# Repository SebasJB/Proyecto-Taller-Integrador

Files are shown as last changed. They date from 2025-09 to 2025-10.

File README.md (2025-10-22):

# Plataforma de interconexión y pruebas del SIWA

## EL-5610 – Taller Integrador

[]()
[]()
[]()
[]()

---

## 1. Introducción

<p align="justify">
Este sprint documenta la construcción física de la PCB del proyecto, desde el barrenado inicial (<em>drill</em>) hasta la soldadura SMD posterior al reflow. El objetivo es registrar, con trazabilidad, cada etapa del proceso junto con criterios de aceptación y evidencias visuales, de manera que la tarjeta quede lista para el plan de pruebas eléctricos y funcionales del siguiente sprint.
</p>

---

## 2. Integrantes

- Samuel Valdivia Mejias
- Sebastian Barrantes Perez
- Christopher Quiros Cisneros

---

## 3. Etapas de fabricación
### 3.1 Drill

La etapa de perforado o drill, consiste en taladrar todos los orificios para pines, tornillos y vías según el archivo de mecanizado. Aquí se definen los diámetros y la precisión de los taladros que conectarán las capas a través de metalización. En la siguiente imagen se observa el resultado del proceso de perforado.

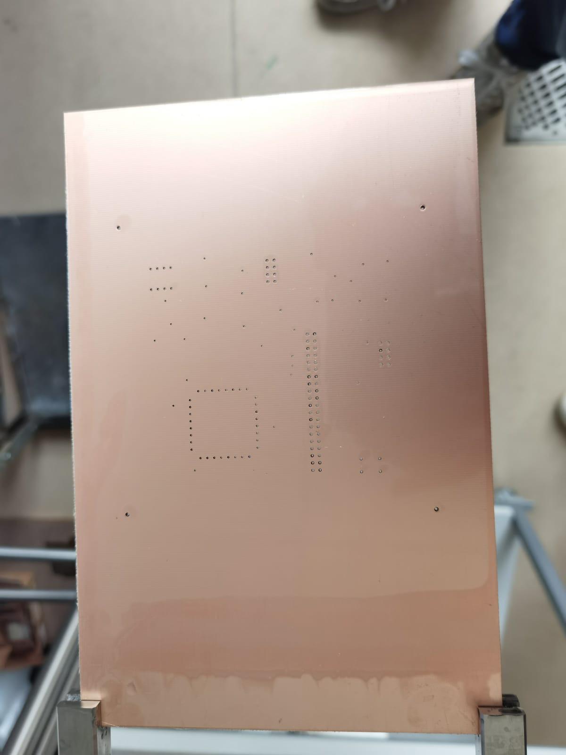
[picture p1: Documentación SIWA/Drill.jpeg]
PCB: Post drill
 <p align="center"> PCB: Post drill </p>

### 3.2 Metalización y Stencil

La metalización recubre las paredes de los orificios con cobre para crear vías eléctricas entre capas. El stencil se usa posteriormente para depositar pasta de soldar de forma precisa sobre pads SMD. En la siguiente imagen se aprecia el tablero después de metalizar.

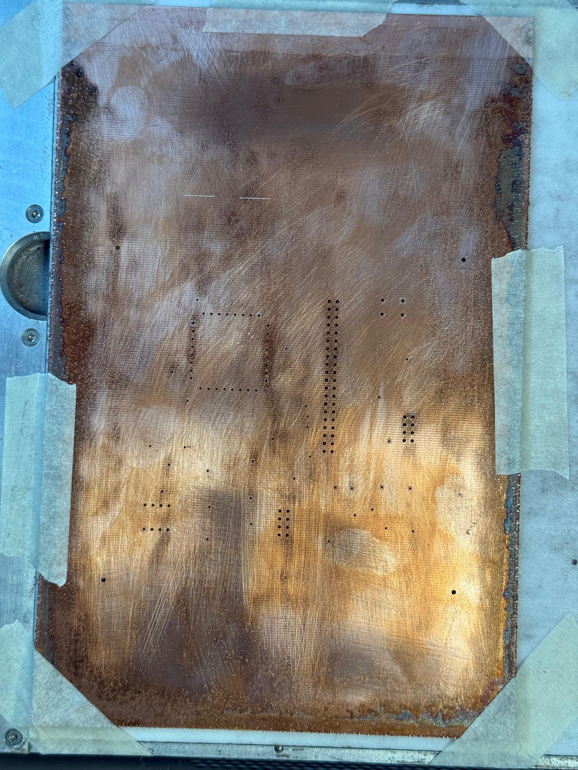
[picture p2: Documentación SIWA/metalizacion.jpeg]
PCB: Post metalizacion
 <p align="center"> PCB: Post metalizacion </p>

### 3.3 Endmill Bottom

El endmill bottom es un fresado de contorno o cavidades realizado por la cara inferior para definir bordes, islas o despejes de cobre mecánicos. En la siguiente imagen se muestra el resultado del fresado inferior.

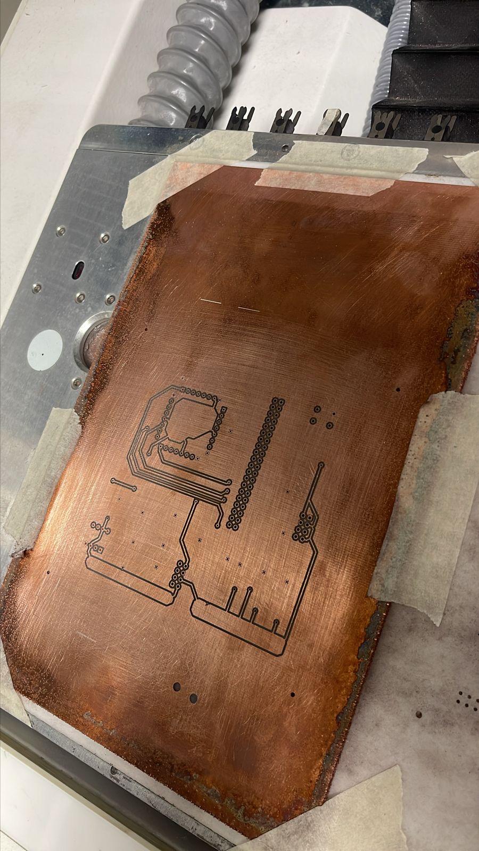
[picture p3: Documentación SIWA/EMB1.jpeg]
PCB: Post Endmill Bottom
 <p align="center"> PCB: Post Endmill Bottom </p>

### 3.4 Endmill Top

El endmill top realiza operaciones de fresado por la cara superior para definir pistas y pads. En las siguientes imágenes se observa el proceso durante la fabricación y el resultado final de la parte superior.

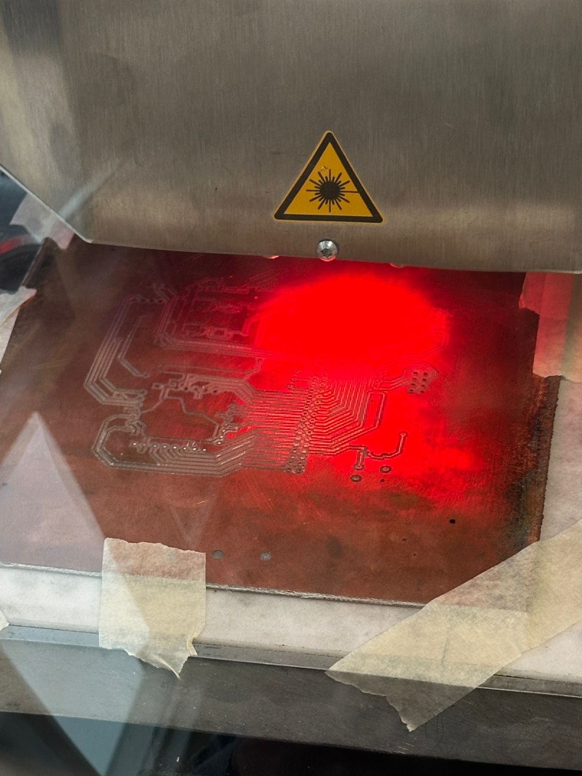
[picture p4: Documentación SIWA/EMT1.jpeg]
PCB: Endmill top durante fabricacion
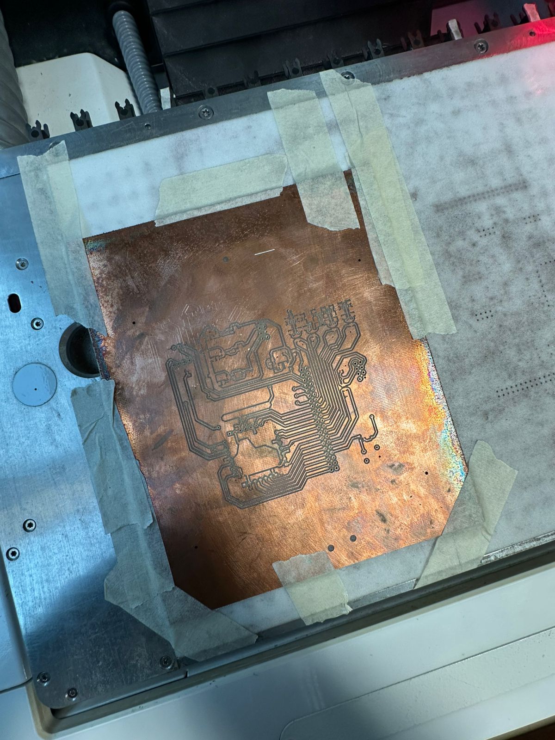
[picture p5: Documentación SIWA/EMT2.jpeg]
PCB: Post Endmill Top
 <p align="center"> PCB: Endmill top durante fabricacion </p>  <p align="center"> PCB: Post Endmill Top </p>

### 3.5 Verificación de aislamientos y cortos

En la verificación eléctrica se inspeccionan aislamientos entre redes y la ausencia de cortocircuitos, ya sea con multímetro o equipo de prueba de continuidad/hi-pot. En las siguientes imágenes se ven distintas revisiones realizadas.

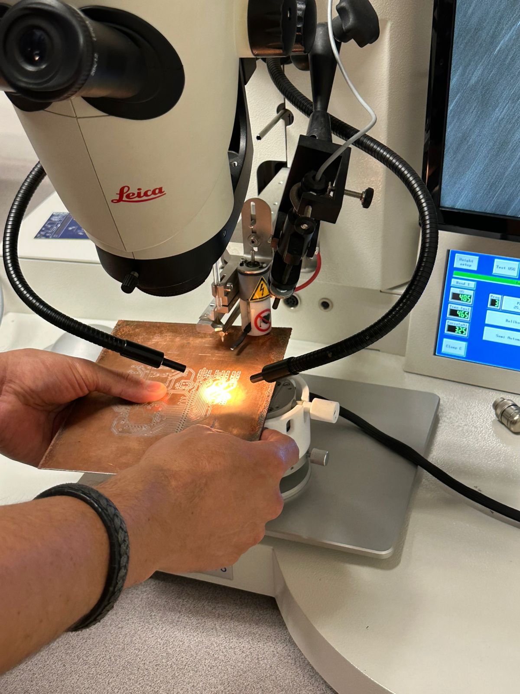
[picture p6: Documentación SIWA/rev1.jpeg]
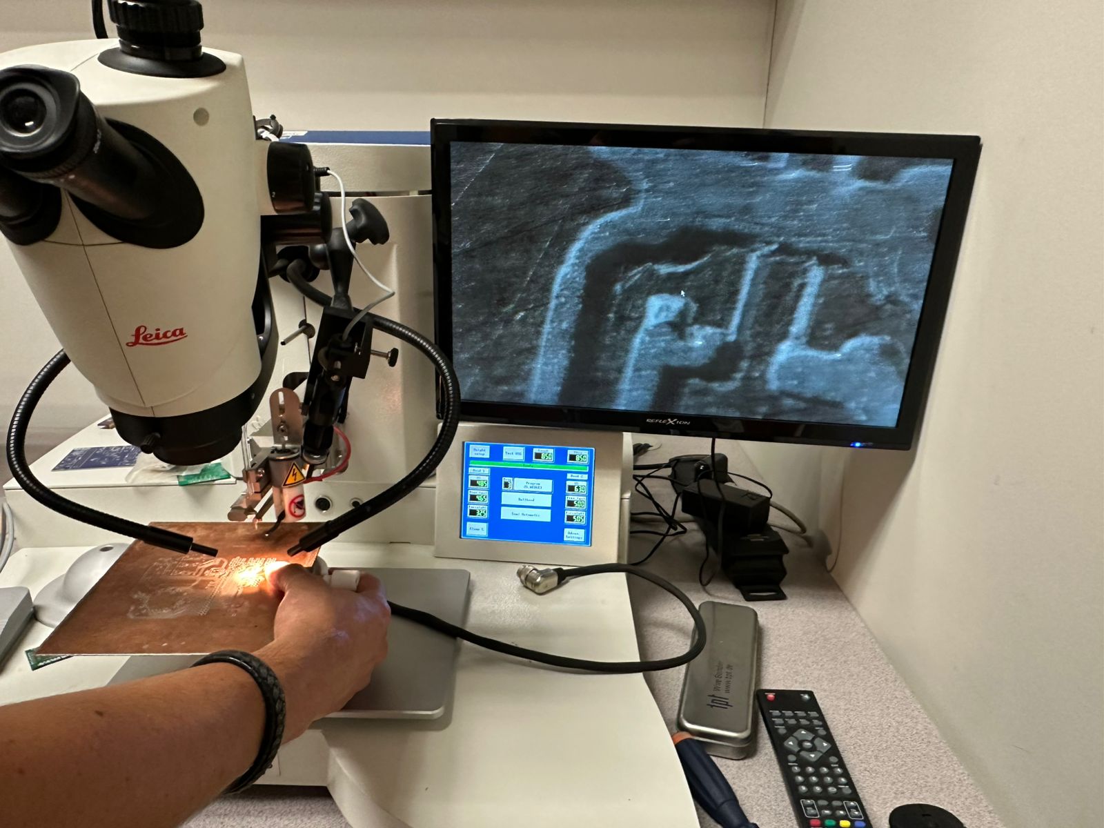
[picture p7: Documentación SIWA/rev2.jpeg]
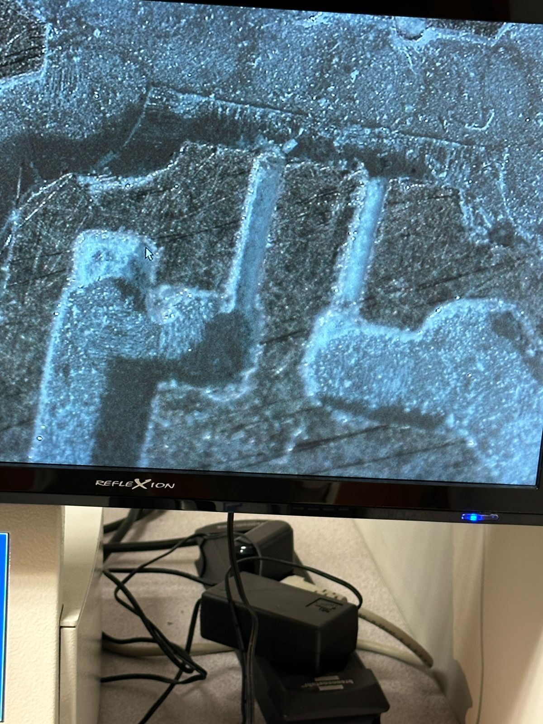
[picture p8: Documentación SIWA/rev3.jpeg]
 <p align="center"> PCB: Revision de cortos </p>  <p align="center"> PCB: Revision de cortos </p>  <p align="center"> PCB: Revision de cortos </p>

### 3.6 Soldermask y Silkscreen

La soldermask protege el cobre expuesto y define ventanas de soldadura sobre los pads; el silkscreen imprime referencias, logos y marcas de orientación. En las siguientes imágenes se muestran las caras superior e inferior tras aplicar soldermask y serigrafía.

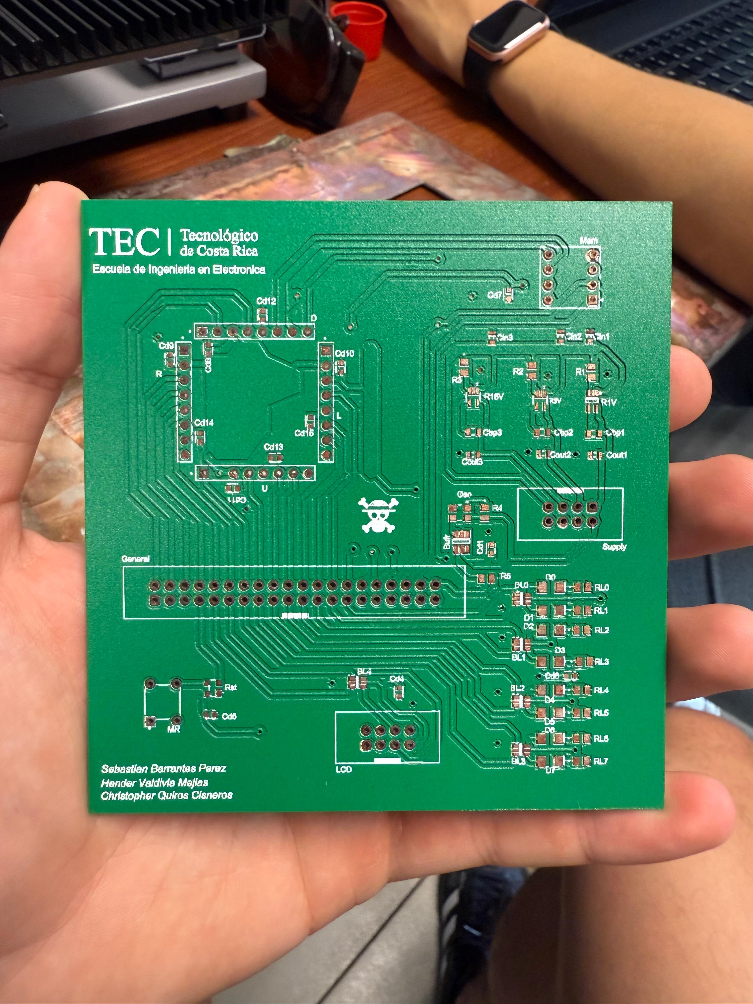
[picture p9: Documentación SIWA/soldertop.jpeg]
PCB: Post Soldermask Top
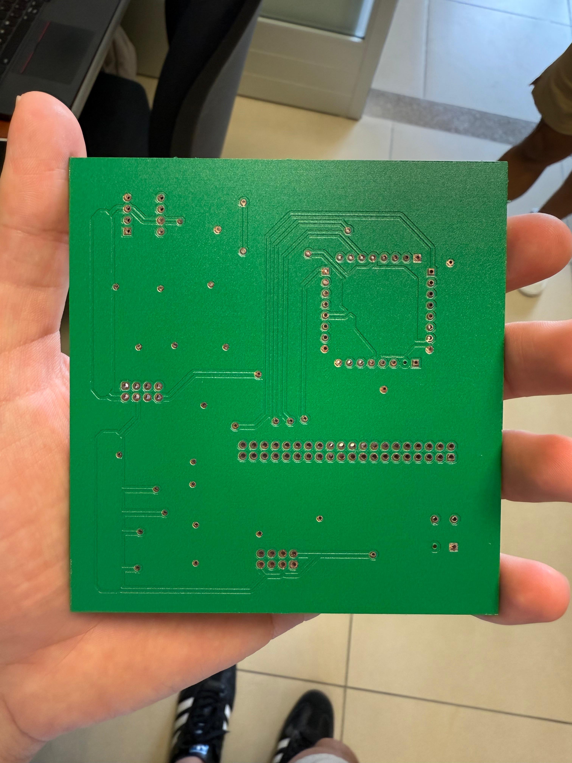
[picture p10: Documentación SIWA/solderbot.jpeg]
PCB: Post Soldermask Bottom
 <p align="center"> PCB: Post Soldermask Top </p>  <p align="center"> PCB: Post Soldermask Bottom </p>

### 3.7 Soldadura SMD

La soldadura SMD comprende el depósito de pasta con stencil, la colocación de componentes y el perfil de reflow en horno. En las siguientes imágenes se aprecia la aplicación de pasta, el pre-ensamble, el paso por horno y el resultado final de soldadura.

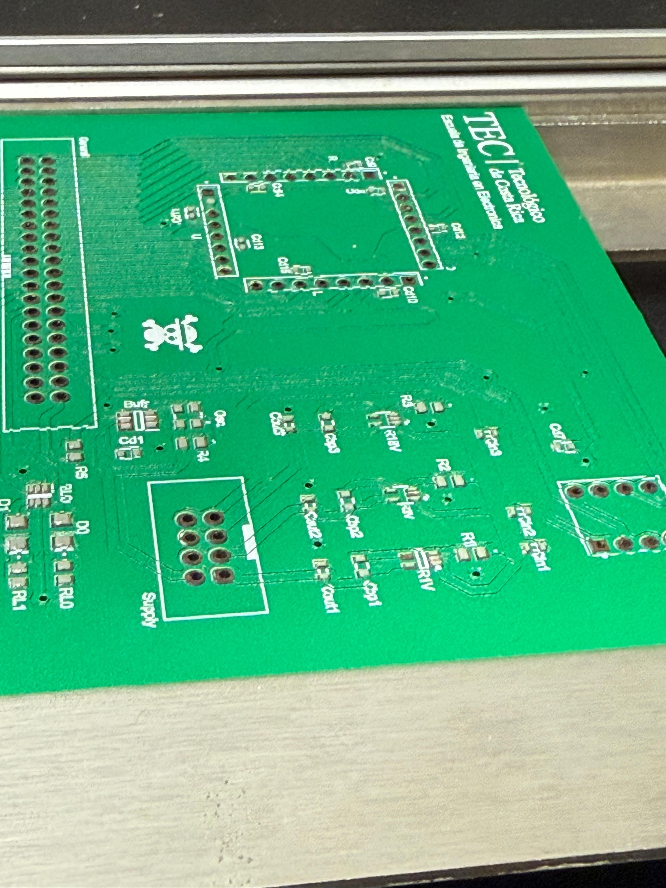
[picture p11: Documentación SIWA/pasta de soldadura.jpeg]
PCB: aplicacion de pasta de soldadura
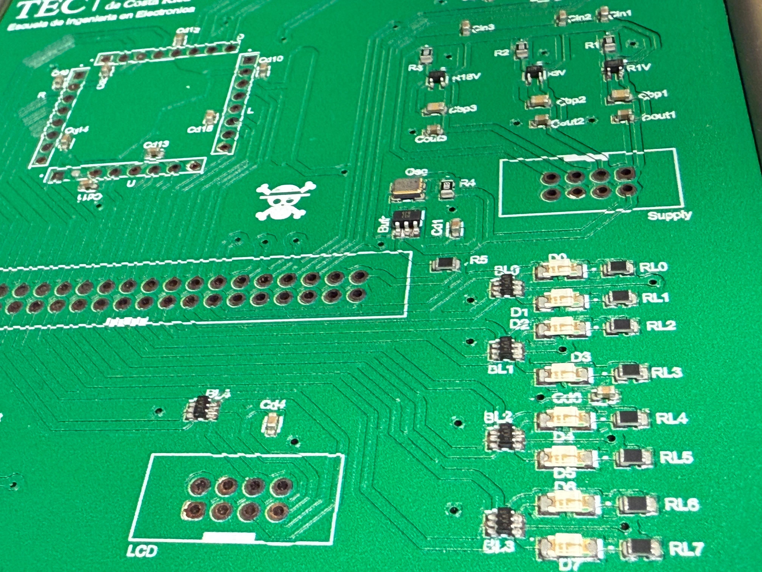
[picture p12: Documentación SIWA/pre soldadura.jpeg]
PCB: Presoldadura, componentes ya colocados
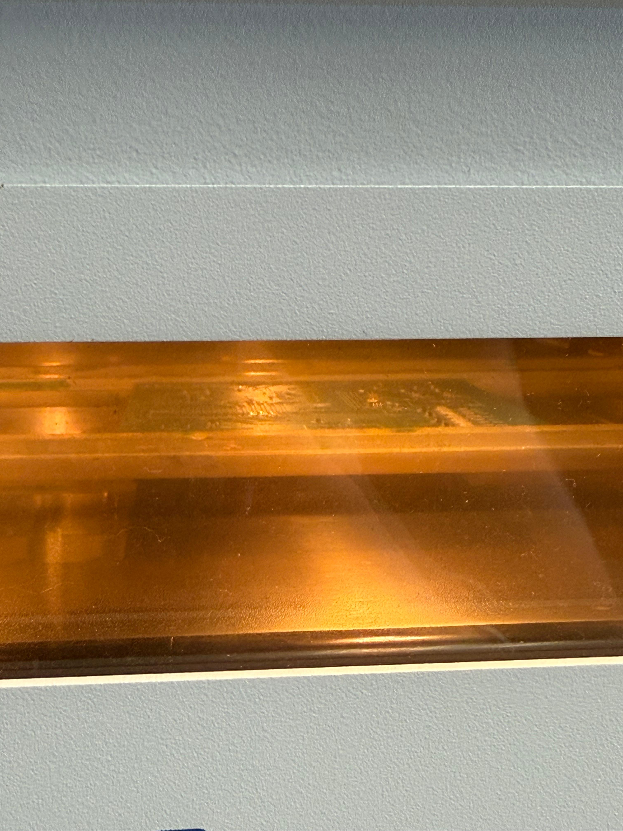
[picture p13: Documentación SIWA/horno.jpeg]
PCB: Proceso de soldado en el horno
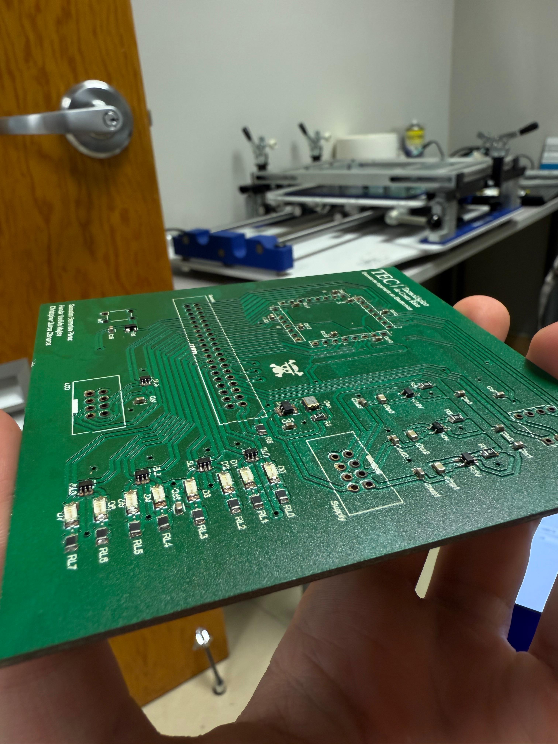
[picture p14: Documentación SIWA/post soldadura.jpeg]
PCB: Post Soldadura
 <p align="center"> PCB: aplicacion de pasta de soldadura </p>  <p align="center"> PCB: Presoldadura, componentes ya colocados </p>  <p align="center"> PCB: Proceso de soldado en el horno </p>  <p align="center"> PCB: Post Soldadura </p>

## 4. Erros y desafios

Durante el proceso de Endmill Top se encontró un corto en el buffer 0 de los LEDs el cual era causado por una mala remoción del cobre en la pista, se procedió a remover con un cincel especial.

Luego durante el proceso de soldadura SMD se generó otro cortocircuito que era causado por el contacto de dos soldaduras diferentes entre el pin de VDD y la salida hacia el LED 4 provocando una falla, luego de removerla con el cincel se pudo solucionar

Se encontró un probloema con los conectores hembra de la interfaz del SIWA que no entran en la placa por ser de forma cuadrada y ligeramente mas ancho que el espacio del hoyo para que entre los pines, se procedió a reducir el tamaño mediante limadura.

## 5. Test Plan – Verificación y Validación de la PCB
<p align="justify"> Este plan de pruebas detalla las verificaciones eléctricas y funcionales realizadas sobre la tarjeta fabricada. Cada prueba se identifica por un código <strong>(T-N)</strong> y busca confirmar la correcta operación de los subsistemas antes y después del montaje del ASIC. Las pruebas se ejecutan siguiendo una secuencia lógica: desde conectividad básica hasta validaciones funcionales completas con firmware de diagnóstico. 
De igual manera, de primer paso, se realizo la prueba del funcionamiento de la memoria:
</p>

<p align="center">
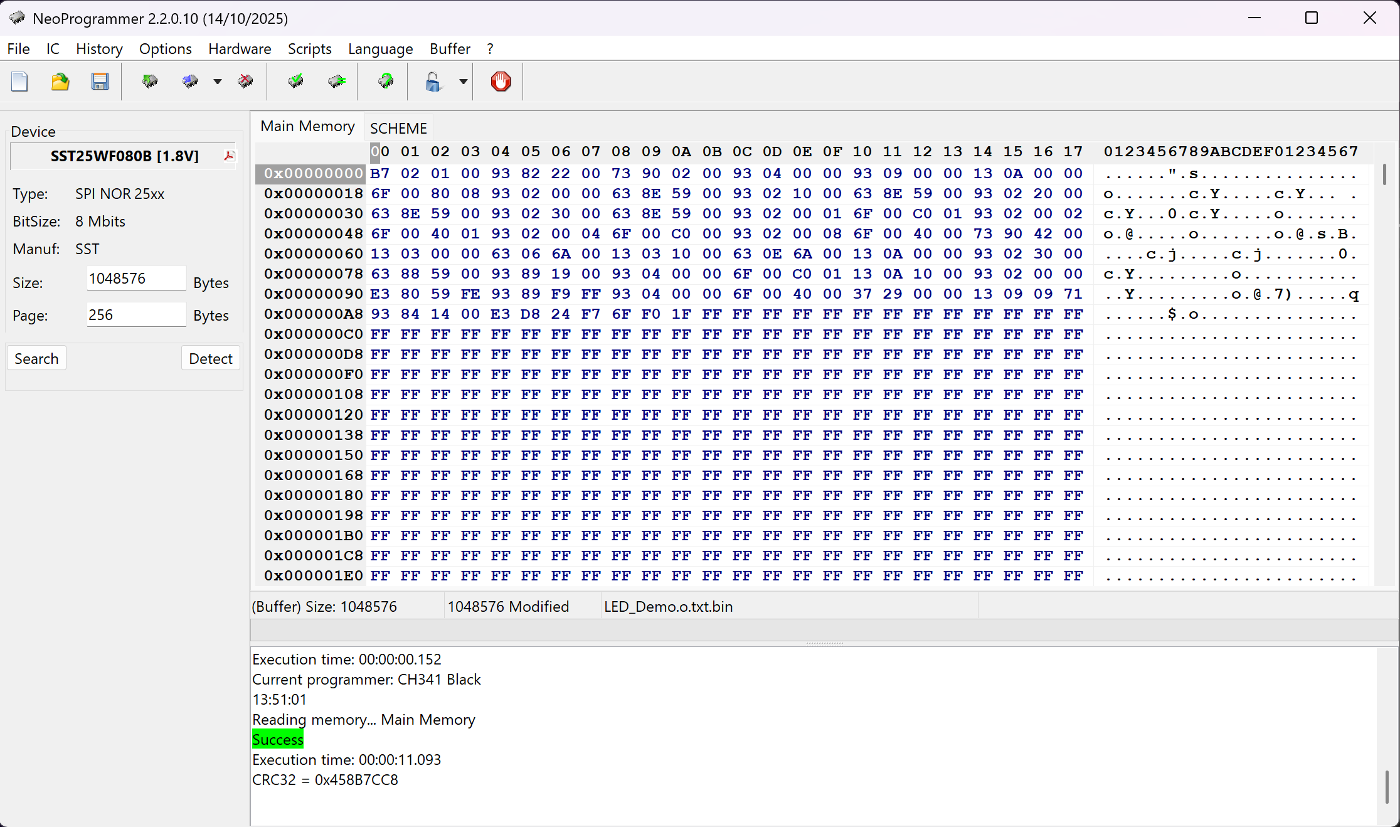
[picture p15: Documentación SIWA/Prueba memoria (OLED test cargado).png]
Prueba memoria (OLED test cargado)
  
</p>
<p align="center">
PCB: Post Soldadura

 ### 5.1. Instrumentación

- Fuente de laboratorio
- Multímetro digital (DMM)
- Osciloscopio 
- Cargas resistivas para 1 V, 1.8 V y 3 V
- Arduino para pruebas dinámicas
- Jumpers, divisores de tensión y convertidores de nivel

### 5.2 Conectividad por headers (T-0)
<p align="justify"> Antes de energizar la placa, se realiza una verificación minuciosa de continuidad utilizando los headers intermedios como puntos de prueba. Se confirma que cada módulo bufferizado (reguladores, LEDs, LCD, reloj y reset) tiene su camino eléctrico completo desde la entrada del buffer hasta la salida hacia la carga, y que no existen puentes inadvertidos a tierra o entre señales contiguas. Con el multímetro en modo continuidad y la placa sin alimentación, se comprueba cada par “entrada ↔ salida”, escuchando el pitido solo cuando corresponde según el esquemático. Se finaliza con una verificación de ausencia de corto entre rieles de alimentación y GND. </p>

**Objetivo:** Verificar continuidad entre headers, buffers y cargas, asegurando que no existan cortos entre rieles.

**Procedimiento:**
- Placa sin energía, DMM en continuidad.  
- Verificar headers intermedios y rieles de alimentación.  
- Confirmar ausencia de corto con GND.

**Criterio:**  
Todos los caminos coinciden con el esquemático y no hay cortos entre rieles.

### 5.3 Fuentes sin carga (T-1)
<p align="justify"> Con la placa sin cargas conectadas, se alimenta desde la fuente de laboratorio con límite de corriente ajustado. Se verifica que los tres reguladores (1.0 V, 1.8 V y 3.0 V) establecen sus tensiones nominales de forma estable y sin rizado excesivo. Se mide cada pista con multímetro (DC) y osciloscopio (AC) observando rizado y picos de arranque.</p>

**Objetivo:** Confirmar tensiones nominales y estabilidad sin carga.

| Riel | Tensión esperada | Ripple máx | Estado |
|:--|:--:|:--:|:--:|
| 3.0 V | 3.00 ± 3 % | < 50 mVpp | ☐ |
| 1.8 V | 1.80 ± 2 % | < 30 mVpp | ☐ |
| 1.0 V | 1.00 ± 2 % | < 20 mVpp | ☐ |

**Procedimiento:**

- Fuente de laboratorio a **Vin = 5.0 V**, GND común.  
- Medir con multímetro en el header de Alimentación:
  - Pin 1 (VDD10)
  - Pin 5 (VDD18)
  - Pin 3 (VDD30) 
- Medir cada pin en su header de salida con Multímetro y osciloscopio (AC acoplado).
  
**Criterio:** Las tres salidas están dentro de tolerancia y con rizado menor al límite.

### 5.4 Fuentes con carga (T-2)
<p align="justify"> Se conectan cargas resistivas a cada pista, una por vez, para validar la capacidad de regulación y estabilidad bajo demanda. Se incrementa la corriente hasta el valor nominal de cada pista y se repiten las mediciones. Luego se aplica un escalón de carga observando la respuesta transitoria: la tensión no debe presentar sobre-/sub-tensión mayores al 5 % ni oscilar. </p>

**Objetivo:** Evaluar regulación bajo corriente nominal y respuesta a transientes.

**Procedimiento:**
**Conexión:**
- Conecta cargas resistivas en protoboard y usar jumpers para conectar de los pines de salida del header a la protoboard:  
  - 10 Ω → VDD10,  
  - 18 Ω → VDD18,  
  - 30 Ω → VDD30.  
- Medir caída de tensión con Multímetro.  
- Realizar un **step-load de 10 % a 100 % a 10 %** y observar overshoot < 5 %.  
 Para el step-load: **Conmutador y resistencias**
- 2 resistencias que representen 10 % y 100 % de carga (R1 y R2).
- 1 transistor NPN (2N2222, 2N3904) o MOSFET N (IRLZ44N, 2N7000).
- Una señal cuadrada con generador de señales.
- Conectar el generador de señales al transistor y luego medir los cambios de tensión con osciloscopio en cada una de las resistencias de carga.

**Criterio:** Tensiones y rizados se mantienen dentro del rango permitido.

### 5.5 Reset (T-3)
<p align="justify"> Se verifica que el circuito de reset genera un pulso limpio y responde ante condiciones de sub-tensión. Con la placa energizada, se mide en el header del reset mientras se acciona el pulsador. El nivel activo debe tener flancos definidos y duración suficiente para un reinicio completo. </p>

**Objetivo:** Verificar forma de pulso

**Procedimiento:**
1. Conecta osciloscopio entre **pin 7 (RSTO)** y **GND**.  
2. Alimenta la placa (Vin = 5 V).  
3. Presiona el pulsador **MR**.  
4. Observa en pantalla:  
   - Pulso activo **bajo** (≈ 100–200 ms).  
   - Nivel alto estable (3 V) tras liberación. 

**Criterio:** Pulso limpio, sin rebotes y a nivel correcto

### 5.6 Reloj de cristal y buffer (T-4)
<p align="justify"> Se verifica que el oscilador arranca correctamente y entrega la frecuencia nominal, con distribución adecuada por el buffer. La señal medida en el header debe tener forma limpia, duty-cycle cercano al 50 % (40–60 % admisible) y frecuencia dentro de la tolerancia del cristal (± 100 ppm ). </p>

**Objetivo:** Confirmar frecuencia y duty-cycle del oscilador con buffer.

**Pines:**  
- **CLK0** → pin 40  
- **GND** → pin 25  
- Alimentación: VDD18 (pin 4 del header de alimentación)

**Procedimiento:**
1. Colocar la sonda del osciloscopio en **pin 40 (CLK0)**.  
2. Alimentar la placa conectando el pin 1 al 2.  
3. Observa forma de onda.
- Alimentar el circuito y medir en el header de salida del buffer (pin 40).  
- Verificar que la frecuencia sea de **20.000 MHz ± 50 ppm**, un ciclo de trabajo entre 40–60 %, amplitud cercana a 3 Vpp.  

**Criterio:** Señal estable, libre de deformaciones y en frecuencia correcta.

### 5.7 LEDs bufferizados con Arduino (T-5)
<p align="justify"> Se valida la etapa de buffer y el camino hacia los LEDs utilizando un Arduino como generador de señales. Con tierra común, se inyectan señales ON/OFF y PWM (1 kHz) desde el header de control. Se observa que cada LED conmute y varíe de brillo sin parpadeos o incoherencias. </p>

**Objetivo:** Validar respuesta de buffers y polaridad de LEDs.

**Procedimiento:**
- GND común entre Arduino y placa.  
- Enviar secuencias de ON/OFF para probar encendido y apagado
- Enviar un PWM de 1 kHz para probar el brillo.
  
**Entradas de control:** pines 27: LED0, 25: LED1, 23: LED2, 21: LED3, 19: LED4, 17: LED5, 15: LED6 y 13: LED7   
**Salida visible:** cada LED D1–D8  
**Alimentación:** VDD30 (pin 6 del header de alimentación) 

**Criterio:** Todos los LEDs encienden, varían brillo y no presentan parpadeo.
### 5.8 LCD/OLED bufferizado con Arduino (T-6)
<p align="justify"> El display se valida mediante el header intermedio, usando el Arduino para generar la secuencia de inicialización y los patrones de prueba. SSe conectan MOSI/SCLK/CS/DC/RST respetando niveles de 3.3 V. Se inicializa el controlador y se muestra un patrón o texto. </p>

**Objetivo:** Confirmar inicialización y escritura básica vía Arduino.
**Pines:**

- LCD0 → pin 9
- LCD1 → pin 11
- Alimentación: VDD30 (pin 4 del header de alimentación)
  
**Procedimiento:**

- Conectar Arduino a SDA/SCL/RES del header con resistencias de pull-up de 4.7 kΩ a pin 9 y 11.
- Usar librerías y comandos básicos del dispositivo en US2066.
- Enviar un PWM de 1 kHz para probar el brillo.

**Criterio:** Pantalla inicializa y muestra texto sin artefactos o pérdida de contraste.

### 5.9 Memoria en base DIP con apoyo de Arduino (T-7)
<p align="justify"> Dado que la memoria no posee header intermedio, se prueba directamente sobre el zócalo DIP con un Arduino. Para memorias seriales (SPI/I²C), se realiza una escritura/lectura de patrones simples (0xAA, 0x55, 0x00, 0xFF). Para memorias paralelas, se controla un subconjunto de direcciones y datos con CE/OE/WE, verificando escritura y lectura correctas. </p>

**Objetivo:** Confirmar lectura/escritura/erase básicos con Arduino.

**Procedimiento:**

- Conectar Arduino a SDA/SCL/RES del header con resistencias de pull-up de 4.7 kΩ.
- Conectar GND común.
- Enviar secuencia SPI para comprobar escritura y lectura
- 
**Criterio:** Coincidencia entre datos escritos y leídos, sin fallas ni comportamiento errático y sin errores en verificación 

### 5.10 Revisión con ASIC montado
<p align="justify"> Con el ASIC soldado y revisado visualmente, se repiten brevemente las pruebas T-1, T-2, T-3 y T-4 bajo carga real. Se busca confirmar que el chip no introduce ruidos ni caídas adicionales. <strong>Criterio de aceptación:</strong> resultados dentro de márgenes definidos en las pruebas base. </p>

### 5.11 Arranque funcional con Siwa (T-8)
<p align="justify"> Con la placa validada eléctricamente, se programa un firmware de diagnóstico mediante la herramienta Siwa. Al encender, debe correr los programas cargados previamente. Se repiten tres ciclos de arranque incluyendo reset y ciclo de poder. <strong>Criterio de aceptación:</strong> comportamiento consistente en los tres intentos, sin bloqueos ni fallos en periféricos. </p>
**Procedimiento:** 

- Programar firmware de diagnóstico (LED heartbeat 1 Hz + texto en LCD).
- Alimentar la placa (Vin = 5 V).

**Observar:**

- LED heartbeat visible.
- Display muestra texto.

### 5.12 Medición de consumo por pista (T-9)
<p align="justify"> Se mide la corriente de cada pista usando los headers de entrada y salida de medición. Se registran condiciones de reposo y actividad . <strong>Criterio de aceptación:</strong> cada riel dentro de ± 10 % del objetivo y sin caídas o rizado fuera de límites definidos en T-1/T-2. </p>
**Procedimiento:**

- Inserta amperímetro en serie con pin correspondiente en el header de alimentación, conectar pines 1, 3 y 5 con 2, 4 y 8 respectivamente, y medir voltaje y corrientes.
- Mide corriente en reposo y durante ejecución del firmware.

## 6. Checklist de cierre del Sprint 3

* [ ] Evidencias fotográficas por etapa en `images/sprint3/`
* [ ] Registro de QC cumplido
* [ ] Test Plan creado y casos críticos ejecutados
* [ ] Incidencias documentadas y acciones definidas

---

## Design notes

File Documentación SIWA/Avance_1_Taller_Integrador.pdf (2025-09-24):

## Instituto Tecnológico de Costa Rica Escuela de Ingeniería Electrónica

# Avance 1: Propuesta de Diseño de la PCB

## EL-5610 Taller Integrador

## Proyecto: Plataforma de interconexión y prueba para Siwa

## Autores: Barrantes Perez Sebastian, Quiros Cisneros Christopher, Valdivia Mejias Samuel

## Grupo: Grupo 1

24/09/2025

## Índice

1. Alcance del Avance 1 | 2
2. Requerimientos y Especificaciones | 3
3. Sprint 1 | 7
4. Sprint 2 | 11
5. Gestión y Planificación (Metodología Ágil) | 17
Referencias | 19

## 1. Alcance del Avance 1

### 1.1. Objetivo del avance

Para el desarrollo de esta primera fase era la de, la realización del desarrollo de la PCB de pruebas para el procesador Siwa, donde el desarrollo de este se realiza en 2 sprints a lo largo de 51 días. La primer etapa del avance 1 consistió en la investigación de los componentes a usar y la realización de los esquemáticos para los diferentes subsistemas del circuito. Para la segunda fase se enfoco en el planteamiento y diseño del PCB a desarrollar físicamente posteriormente.

### 1.2. Entregables incluidos

Esquemático preliminar por bloques (PDF/imagenes). Reglas de diseño y stackup preliminar.
BoM preliminar.
Layout inicial (capturas de capas/zonas críticas).
Matriz de trazabilidad: requerimiento → implementación en PCB.

## 2. Requerimientos y Especificaciones

### 2.1. Resumen de especificaciones del proyecto

El sistema consta de 6 subsistemas principales los cuales fueron solicitados para la prueba completa del funcionamiento del procesador Siwa. Para el desarrollo del sistema se brindo el modelo para cada uno de los componentes principales, para poder realizar la investigación previa y así realizar primeramente la interconexión de estos con los componentes pasivos necesarios para su funcionamiento.
Una vez realizado dichas conexiones de los subsistemas, se procede al planteamiento y diseño total de la conexión final de todo el sistema para así poder paso al diseño del PCB del sistema para el sprint 2.

### 2.2. Tabla de componentes seleccionados

Función | Dispositivo | Componentes princi-
pales (modelos usados)

Componentes pasivos
(modelos usados)
Alimentación | Reguladores | MAX8510EXK30+T
(3.0V);
MAX8510EXK18+T
(1.8V);
TPS71710DCKT (1.0V)
10 nF | C0G | 0603 | TDK
CGA3E1C0G2A103J080AC;
0.1 µF | X7R | 0603 | TDK
C1608X7R1H104K080AA;
4.7 µF | X5R | 0805 | Mura-
ta GRM21BR61A475KA12; R
100 k ±0.1 % 0805 Vishay
PEP0805Y1003BNTA.
Señal de reloj Oscilador c/ cristal bufferizado

Abracon
ASE3-20.000MHZ-KT
(XO 20 MHz); Microchip
PL133-37 (SOT-23-6)
C | desacople | 10 nF
C0G | 0603 | TDK
CGA3E1C0G2A103J080AC;
R | serie | de | terminación
33–49.9 Ω 0603.
Memoria externa | Flash SPI | Microchip SST25WF080B
(8 Mbit); Zócalo DIP-8
TE 1-2199298-2
R | pull-up | 10 k | 0603
RC0603FR-0710KL | en | /CS
; C 0.1 µF X7R 0603 TDK
C1608X7R1H104K080AA junto
a VCC.
Indicadores | LEDs | bufferiza-
dos
LED | azul | 0402 | QT
Brightek | QBLP595-IB;
Buffer | Schmitt | NXP
74LVC2G17GW,125; Conector encajonado 1×8
Würth 61200821621
R | LED | 1 k | 0402
RC0402FR-071KL; | C | des-
acople | para | el | buffer
0.1 µF | X7R | 0603 | TDK
C1608X7R1H104K080AA.
Interfaz Siwa | Headers | Samtec
TS-108-T-A-1-ND
(1×8) × 4 pcs

Resistencias de pull: 10 k 0603 RC0603FR-0710KL; C de protección.
Pantalla | LCD/OLED | c/
buffer

Newhaven
NHD-0216MW-IB3; Buffer
NXP 74LVC2G17GW,125;
Conector | encajo-
nado | 1×8 | Würth
61200821621

C desacople 0.1 µF X7R 0603 TDK C1608X7R1H104K080AA
; R 22–47 Ω 0603.

Conector externo Header 2×20 | CMP
CMP-1502-00015-1

R pull-ups/pull-downs: 10 k
0603 | RC0603FR-0710KL;
C 0.1 µF X7R 0603 TDK
C1608X7R1H104K080AA.

### 2.3. Lista de Materiales (BoM) Preliminar

La lista de materiales preliminar o por su nombre en ingles, bill of materials (BoM), se genero primeramente para el sprint 1, pero sufrió cambios en la finalización del sprint 2 debido a que hubo cambios en la cantidad de los capacitores usadors.

Designadores | Cant | Modelo | Descripción
Header Alimentacion, LCD | 2 | 61200821621
BL0, BL1, BL2, BL3, BL4 | 5 | 74LVC2G17GW,125 | Integrated Circuit
Buffer_CLK | 1 | PL133-37TI | Integrated Circuit
Cbp1, Cbp2, Cbp3 | 3 | 10nF | Cap Ceramic 10nF 100V C0G 5 % Pad SMD 0603 +125°C Automotive T/R
Cd1, Cd2, Cd3, Cd4, Cd5, Cd6, Cd7 | 7 | 0.1uF | KGM15BR71H104JT Cap Cer 0.1UF 50V X7R 0603
D0, D1, D2, D3, D4, D5, D6, D7 | 8 | QBLP595-IB | LED BLUE CLEAR 0402 SMD
MemorySocket | 1 | 1-2199298-2 | CONN IC DIP SOCKET 8POS TIN
MR | 1 | B3F-1000 | Tactile Switch, SPST-NO, 0.05 A, 5 to 24 V, -25 to 70 degC, 4-Pin THD, RoHS, Bulk
Oscilador | 1 | ASE3-20.000MHZ-KT XTAL OSC XO
| | | 20.0000MHZ CMOS SMD
P1 | 1 | Header General
R1, R2, R3, R4 | 4 | 100k | PEP0805Y1003BNTA Resistor High Precision Thin Film 0805 100k Ohm 0.1 % 1/2W ±10ppm/°C Molded T/R
R5 | 1 | 50 | PEP0805Y1003BNTA Resistor High Precision Thin Film 0805 50 Ohm 0.1 % 1/2W ±10ppm/°C Molded T/R
Regulador 1V | 1 | TPS71710DCKT | Single Output High PSRR LDO, 1...IQ, 5-pin SC70 (DCK), -40 to 85 degC, Green (RoHS & no Sb/Br)
Regulador 1.8V | 1 | MAX8510EXK18+T | IC REG LINEAR 1.8V 120MA SC70-5
Regulador 3V | 1 | MAX8510EXK30+T | IC REG LINEAR 3V 120MA SC70-5
Reset | 1 | APX812-29UG-7 | I_O=20mA

Designadores | Cant | Modelo | Descripción
RL0, RL1, RL2, RL3, RL4, RL5, RL6, RL7 | 8 | 20
SIWA_D, SIWA_L, SIWA_R, SIWA_U | 4 | PPTC081LFBN-RC | Conector interfaz SIWA
Capacitores adicionales | 6 | 0.1uF | Capacitor cerámico X7R 0603 (desacople general)

## 3. Sprint 1

Para la inicialización del proyecto, se planteo este primer sprint con la finalidad de realizar la investigación previa de los componentes a usar, planteamiento de los esquemáticos del sistema y del esquemático de todo el sistema interconectado.
La conexion de los componentes de alimentacion, senal de reloj, indicadores y LCD se realizaron en base a las recomendaciones de circuitos en sus respectivos datasheets. Para la interfaz del Siwa y de la memoria externa se realizaron conjuntamente ya que estos iban conectados directamente entre si, ya que la memoria usara los pines

### 3.1. Esquemáticos por subsistema

El esquemático preliminar consta de las siguientes partes que se enumeraran a continuación:
1. Alimentación: reguladores y redes de desacople.
2. Reloj: oscilador + buffer + red de 50 Ω.
3. Siwa: mapeo de pines según empaquetado, reset con APX812-29UG7 + pulsador B3F-1000.
4. Memoria SPI: SST25WF080B + base DIP-8.
5. Indicadores: 8 LEDs con buffers y resistencias.
6. Interfaz externa: header 2x20; señales expuestas (MAIP, POC, SPI, UART, CLK, RESET).
7. Pantalla: interfaz LCD/OLED con buffers y conectores.
Para una mayor facilidad de lectura, se dividió por cada subsistema y las respectivas nets a la que va cada entrada y salida de los respectivos sistemas.

### 3.1.1. Memoria externa e interfaz Siwa

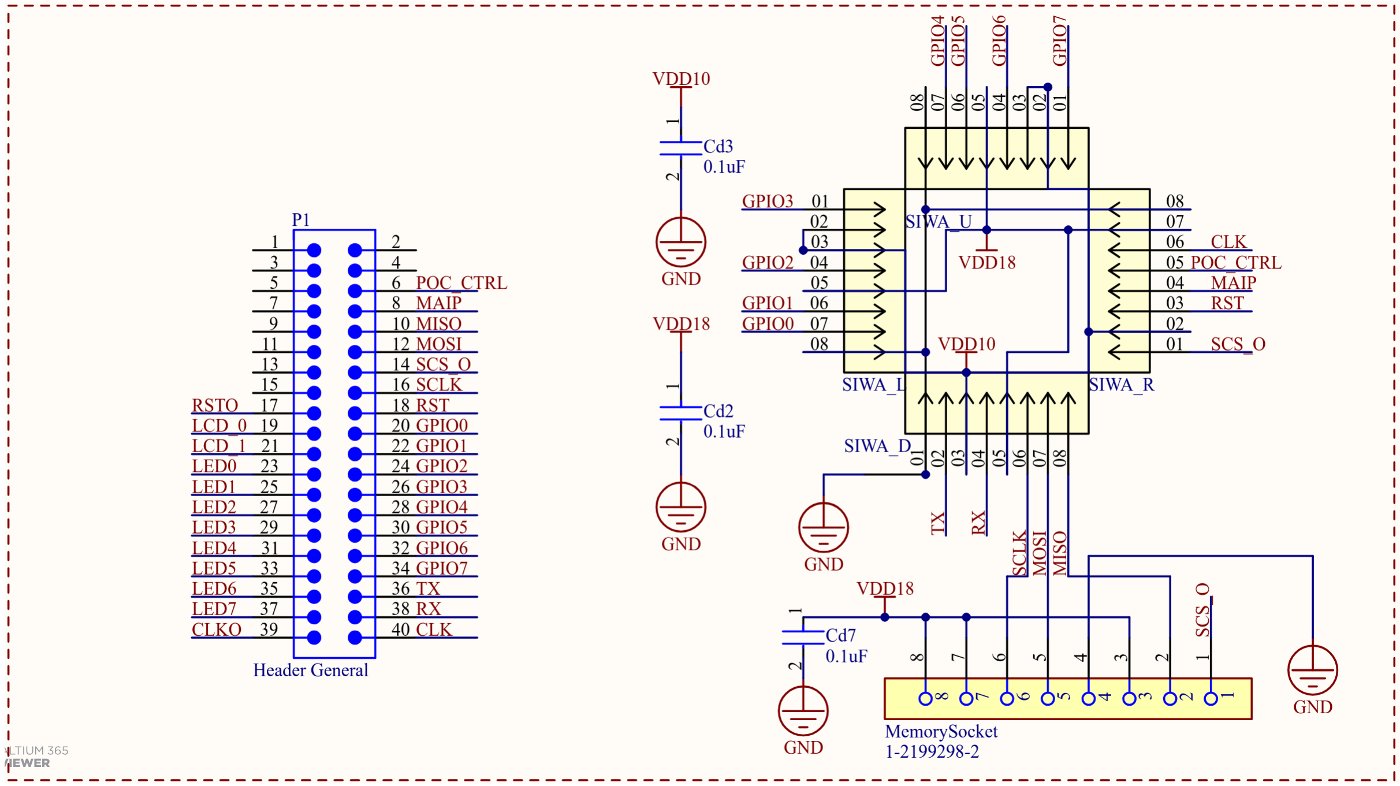
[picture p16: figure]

Figura 1: Esquemático de la interfaz del Siwa y la memoria externa

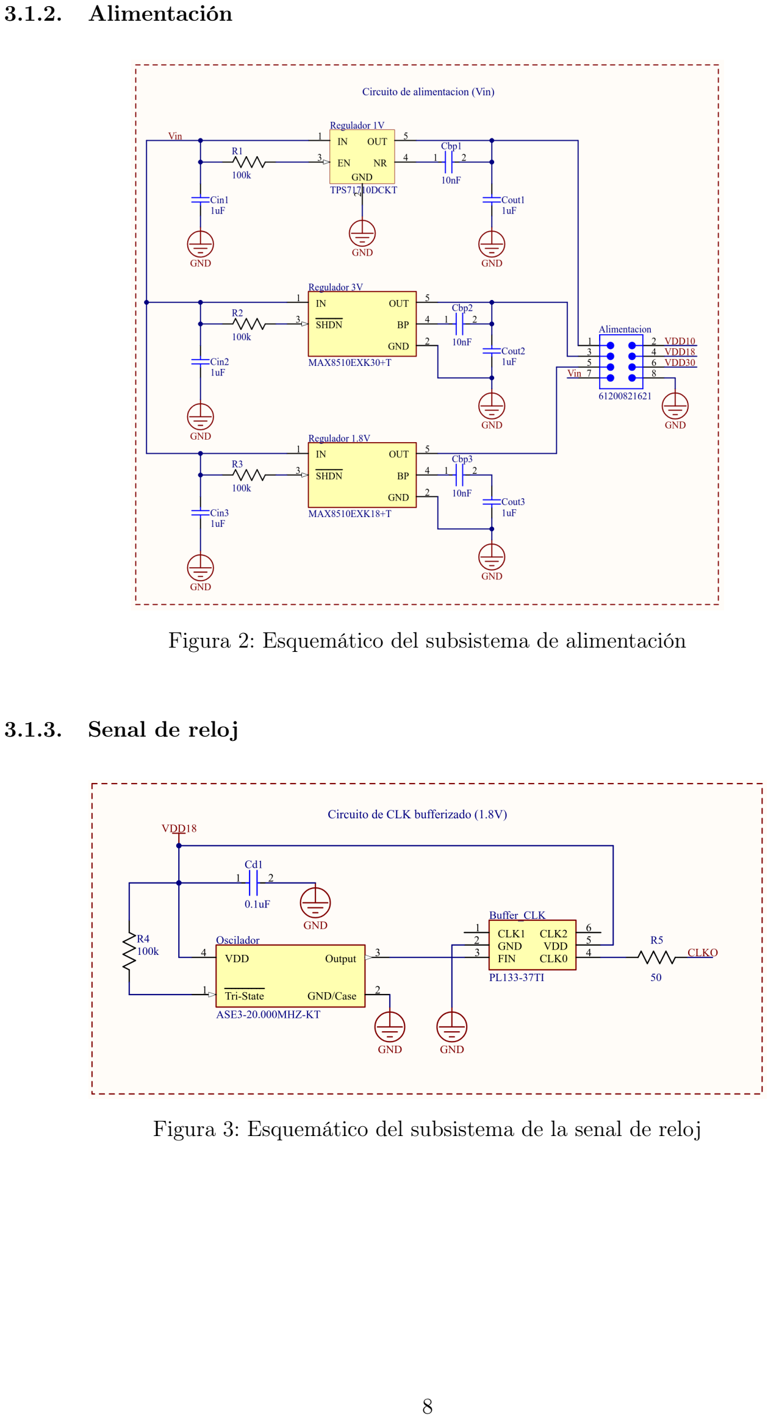
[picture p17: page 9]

### 3.1.2. Alimentación

Figura 2: Esquemático del subsistema de alimentación

### 3.1.3. Senal de reloj

Figura 3: Esquemático del subsistema de la senal de reloj

### 3.1.4. LEDs

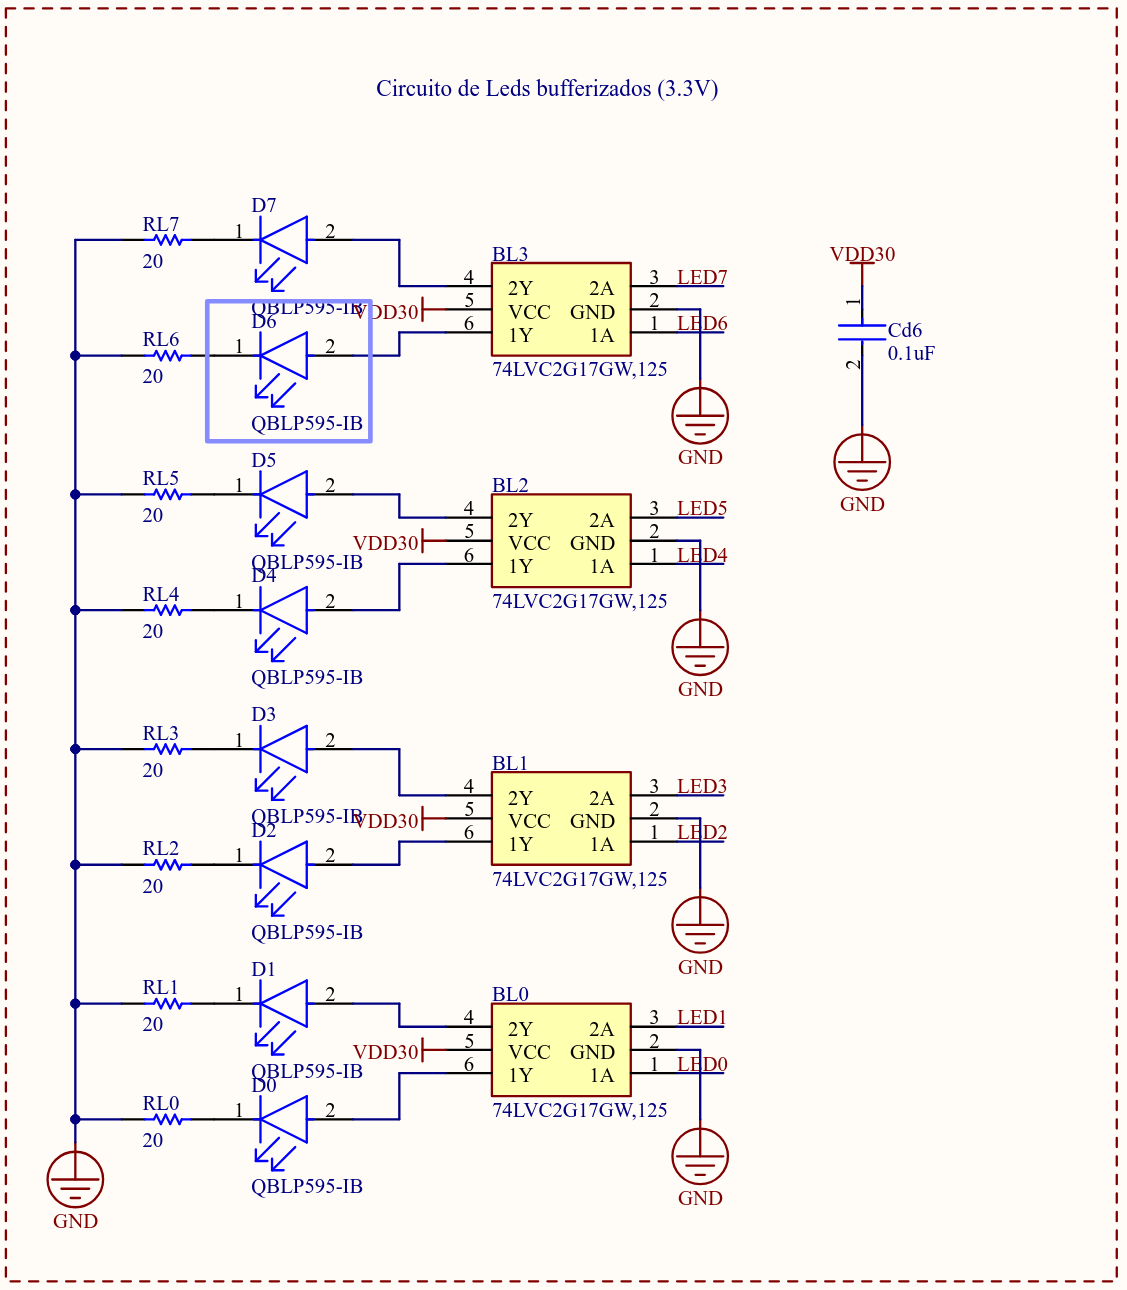
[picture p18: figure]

Figura 4: Esquemático del subsistema de los LEDs

### 3.1.5. Pantalla LCD

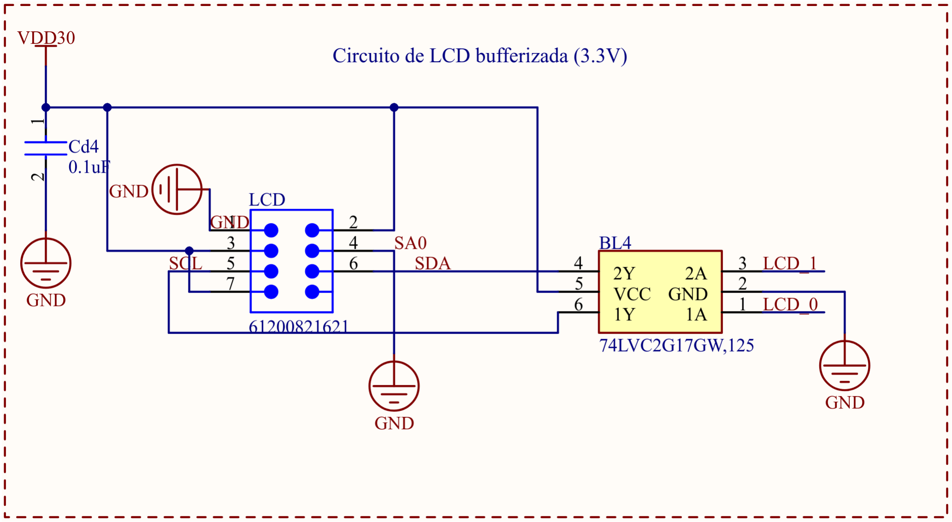
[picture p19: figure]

Figura 5: Esquemático del subsistema del LCD

### 3.2. Conexiones del Siwa

Pin | Conectado a | Pin | Conectado a
1 | N/A | 33 | N/A
2 | N/A | 34 | N/A
3 | N/A | 35 | N/A
4 | N/A | 36 | SCS → P1:SCS_O → Memory Soc-
| | | ket pin 1 (SCS_O)
5 | → GPIO3 → LED3 | 37 | VDD
6 | VDD | 38 | RESET → P1:RST
7 | VDD | 39 | MAIP → P1:MAIP
8 | → GPIO2 → LED2 | 40 | POC_CONTROL | →
| | | P1:POC_CTRL
9 | VDD_IO | 41 | VSS
10 | → GPIO1 → LED1 | 42 | CLK → P1:CLK
11 | VSS | 43 | VSS
12 | VSS | 44 | VDD_IO
13 | → GPIO0 → LED0 | 45 | N/A
14 | N/A | 46 | N/A
15 | N/A | 47 | N/A
16 | VSS PACKAGE SUBSTRATE | 48 | VSS PACKAGE SUBSTRATE
17 | N/A | 49 | N/A
18 | N/A | 50 | N/A
19 | N/A | 51 | N/A
20 | N/A | 52 | N/A
21 | UART_TX → P1:TX | 53 | → GPIO7 → LED7
22 | VDD | 54 | VDD
23 | VSS | 55 | VDD
24 | UART_RX → P1:RX | 56 | → GPIO6 → LED6
25 | VDD_IO | 57 | VDD_IO
26 | SCLK → P1:SCLK → Memory Soc-
| ket pin 6 (SCLK) | 58 | → GPIO5 → LED5
27 | VSS | 59 | VSS
28 | MOSI → P1:MOSI → Memory Soc-
| ket pin 5 (MOSI) | 60 | VSS
29 | MISO → P1:MISO → Memory Soc-
| ket pin 4 (MISO) | 61 | → GPIO4 → LED4
30 | N/A | 62 | N/A
31 | N/A | 63 | N/A
32 | VSS PACKAGE SUBSTRATE | 64 | VSS PACKAGE SUBSTRATE

## 4. Sprint 2

### 4.1. Stackup y reglas de diseño (DRC)

Stackup preliminar
Leyenda del stack: Layer Stack Legend.
Top Overlay: Tipo Legend, Gerber GTO.
Top Solder (Surface Material): Espesor 0.03 mm, Material dieléctrico SM-001, Tipo Solder Mask, Gerber GTS.
Top Layer: Material CF-004, Espesor 0.04 mm, Tipo Signal, Gerber GTL. Dielectric: Espesor 0.32 mm, Material dieléctrico FR-4, Tipo Dielectric.
Bottom Layer: Material CF-004, Espesor 0.04 mm, Tipo Signal, Gerber GBL. Bottom Solder (Surface Material): Espesor 0.03 mm, Material dieléctrico SM-001, Tipo Solder Mask, Gerber GBS.
Bottom Overlay: Tipo Legend, Gerber GBO.
Espesor total: 0.44 mm.

Reglas
Anchos de vías: 0.381 mils
Anchos de vías de alimentación: 0.5 mils clearance mínimo: 0.25 mils
Diámetro de los orificios: 0.20 mils Pads: 0.25 mils

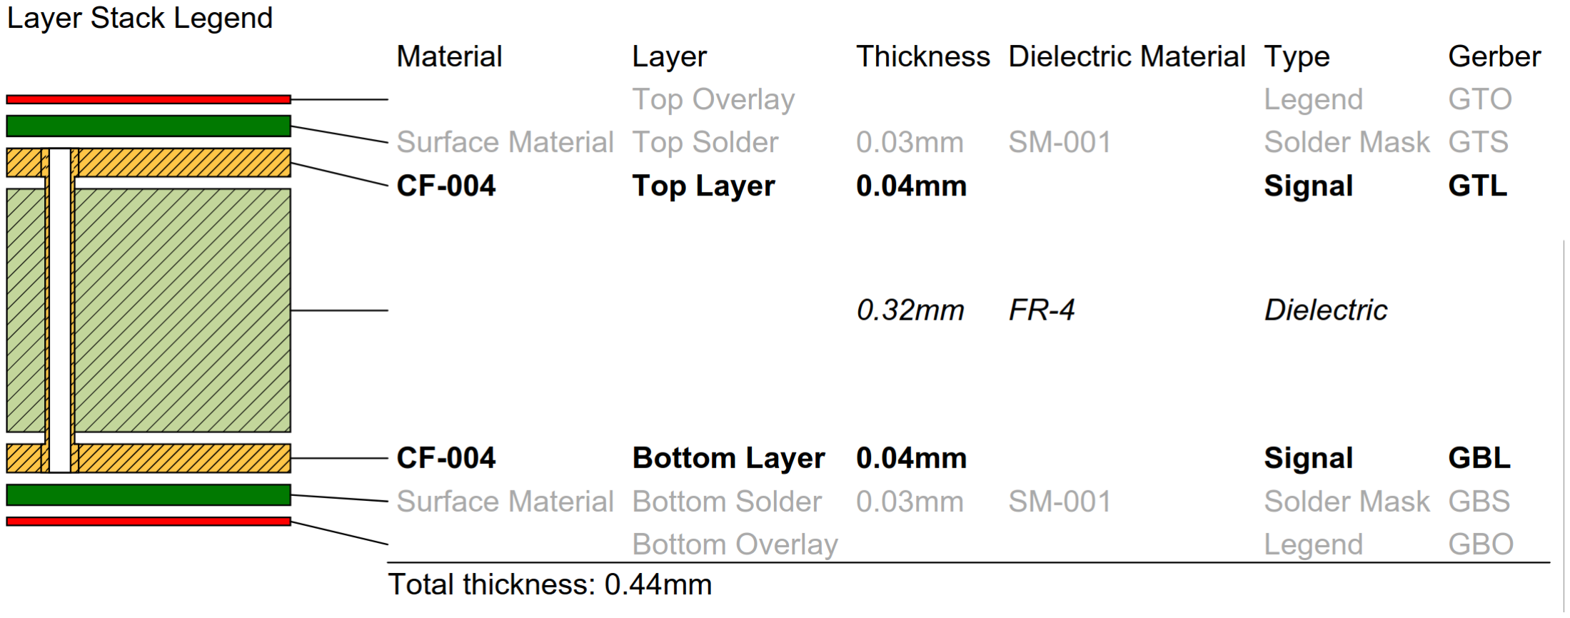
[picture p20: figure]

Figura 6: Diagrama de stackup preliminar

### 4.2. Layout Preliminar (PCB)

Posterior a un amplio periodo de diseño, interconexión y depuración de errores, se concluyó el diseño del PCB. El esquema y la asignación de pines quedaron determinados, se determinaron y validaron las reglas del diseño con el stackup objetivo y se consolido el BoM para fabricación. En el Sprint 3 se procederá al ensamblaje y validación funcional inicial.
Para una visualización clara del resultado, el PCB se presentará separado en sus 2 layers (Top y Bottom), mostrando ruteado, polígonos y zonas críticas y también sus vistas 3D para apreciar relieve, serigrafía y ubicacion de los componentes.

### 4.2.1. Capa superior

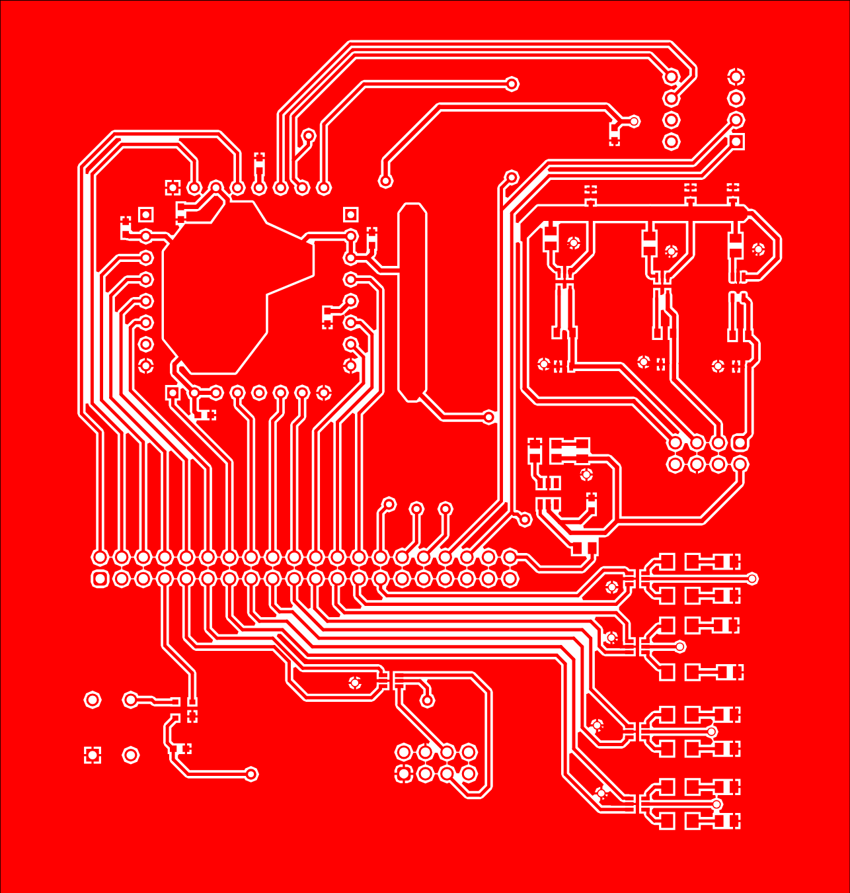
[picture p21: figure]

Figura 7: Diagrama del layer superior

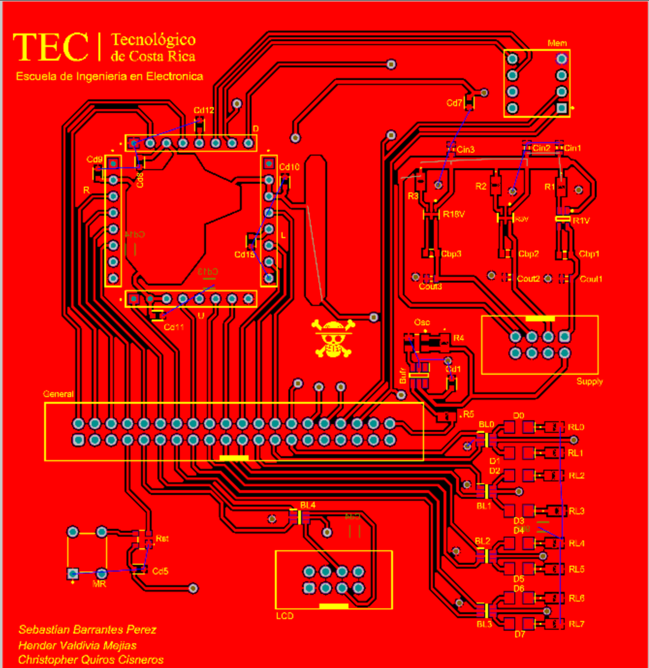
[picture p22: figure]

Figura 8: Diagrama del layer superior con componentes

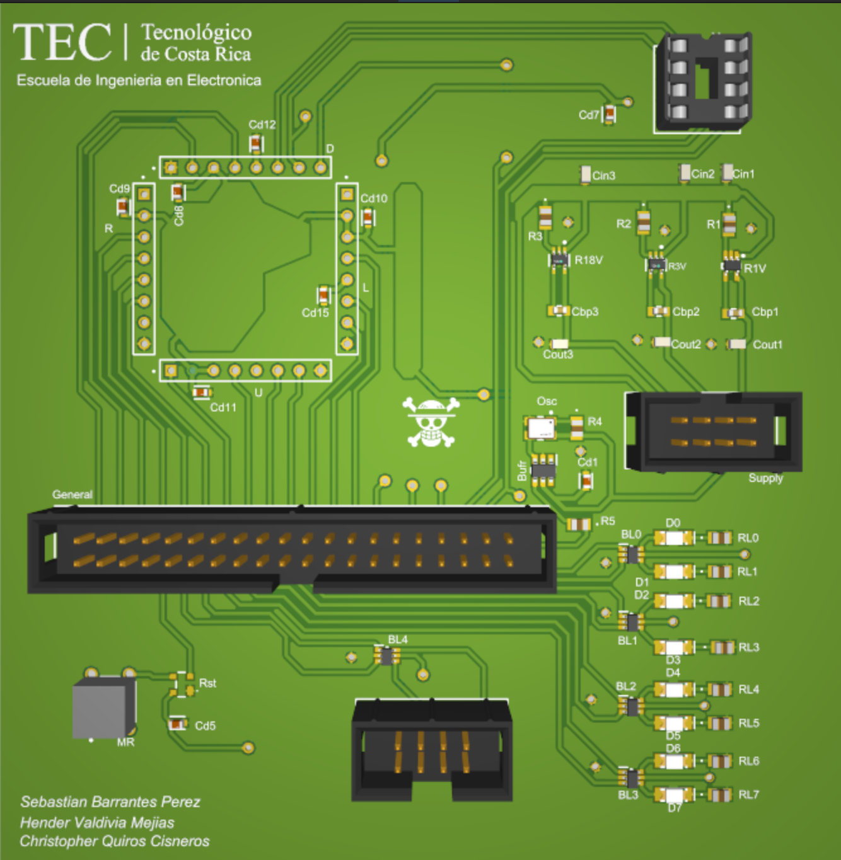
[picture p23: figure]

Figura 9: Diagrama 3D del layer superior con componentes

### 4.2.2. Capa inferior

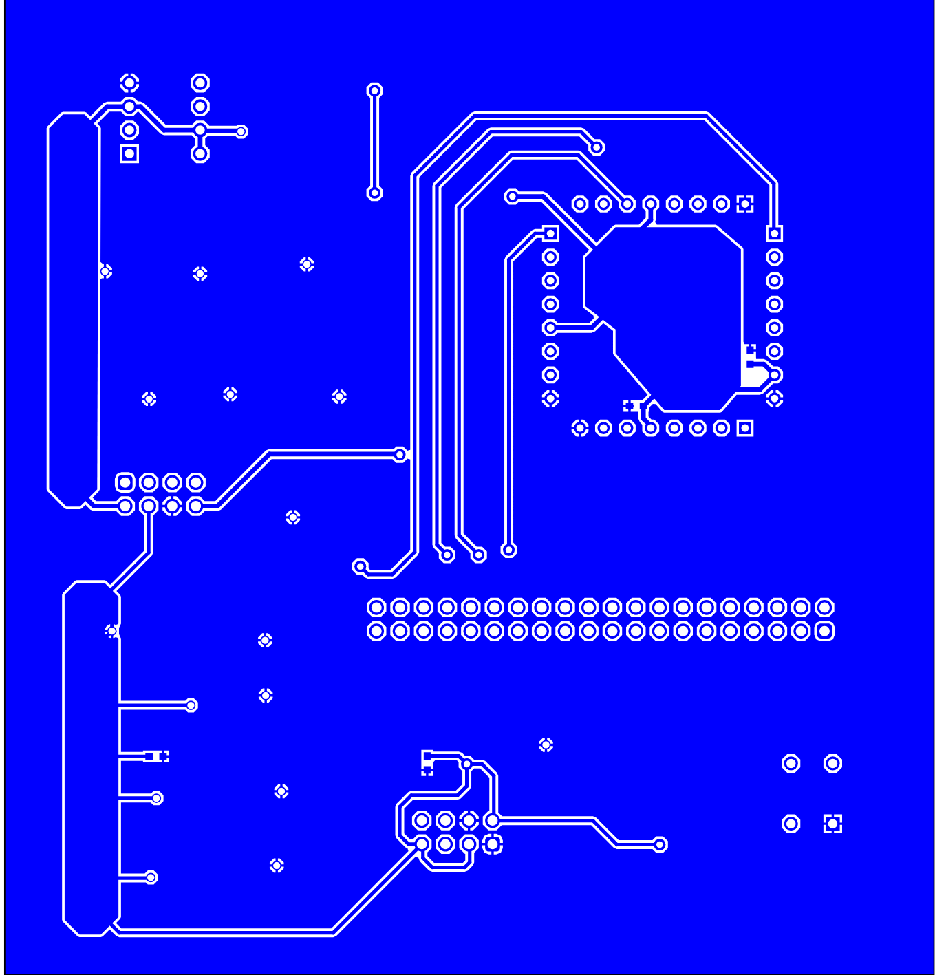
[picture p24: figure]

Figura 10: Diagrama del layer inferior

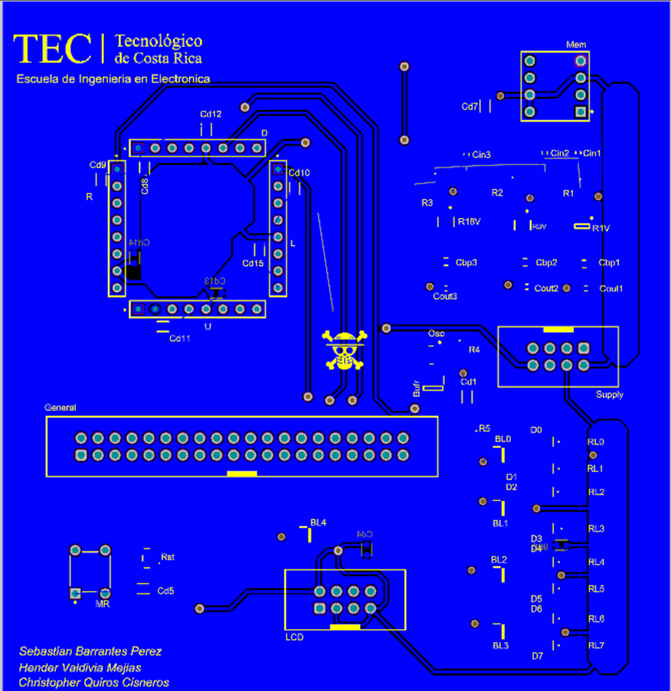
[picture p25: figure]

Figura 11: Diagrama del layer inferior con componentes

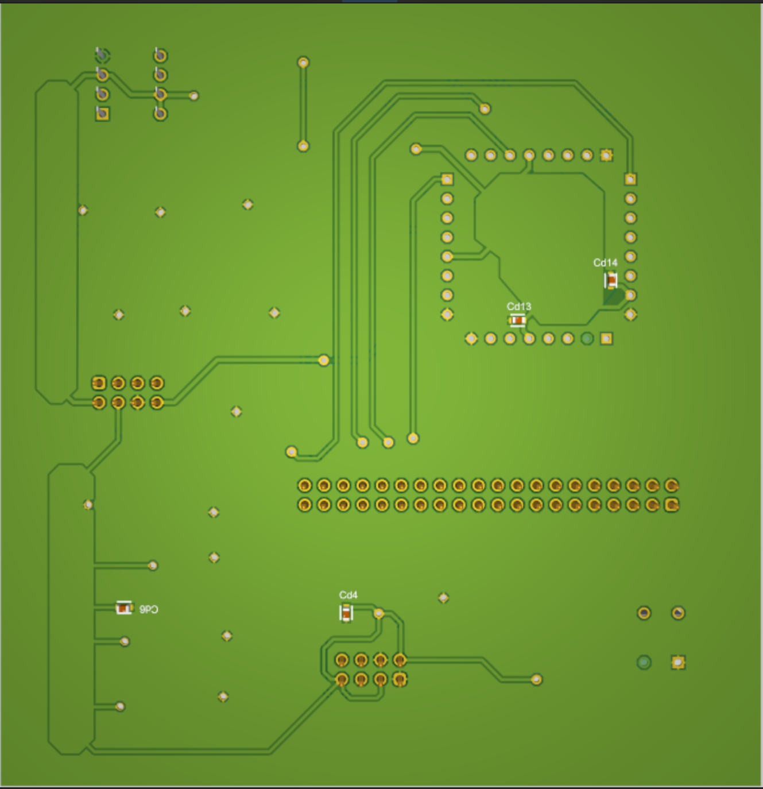
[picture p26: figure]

Figura 12: Diagrama 3D del layer inferior con componentes

### 4.2.3. Vistas

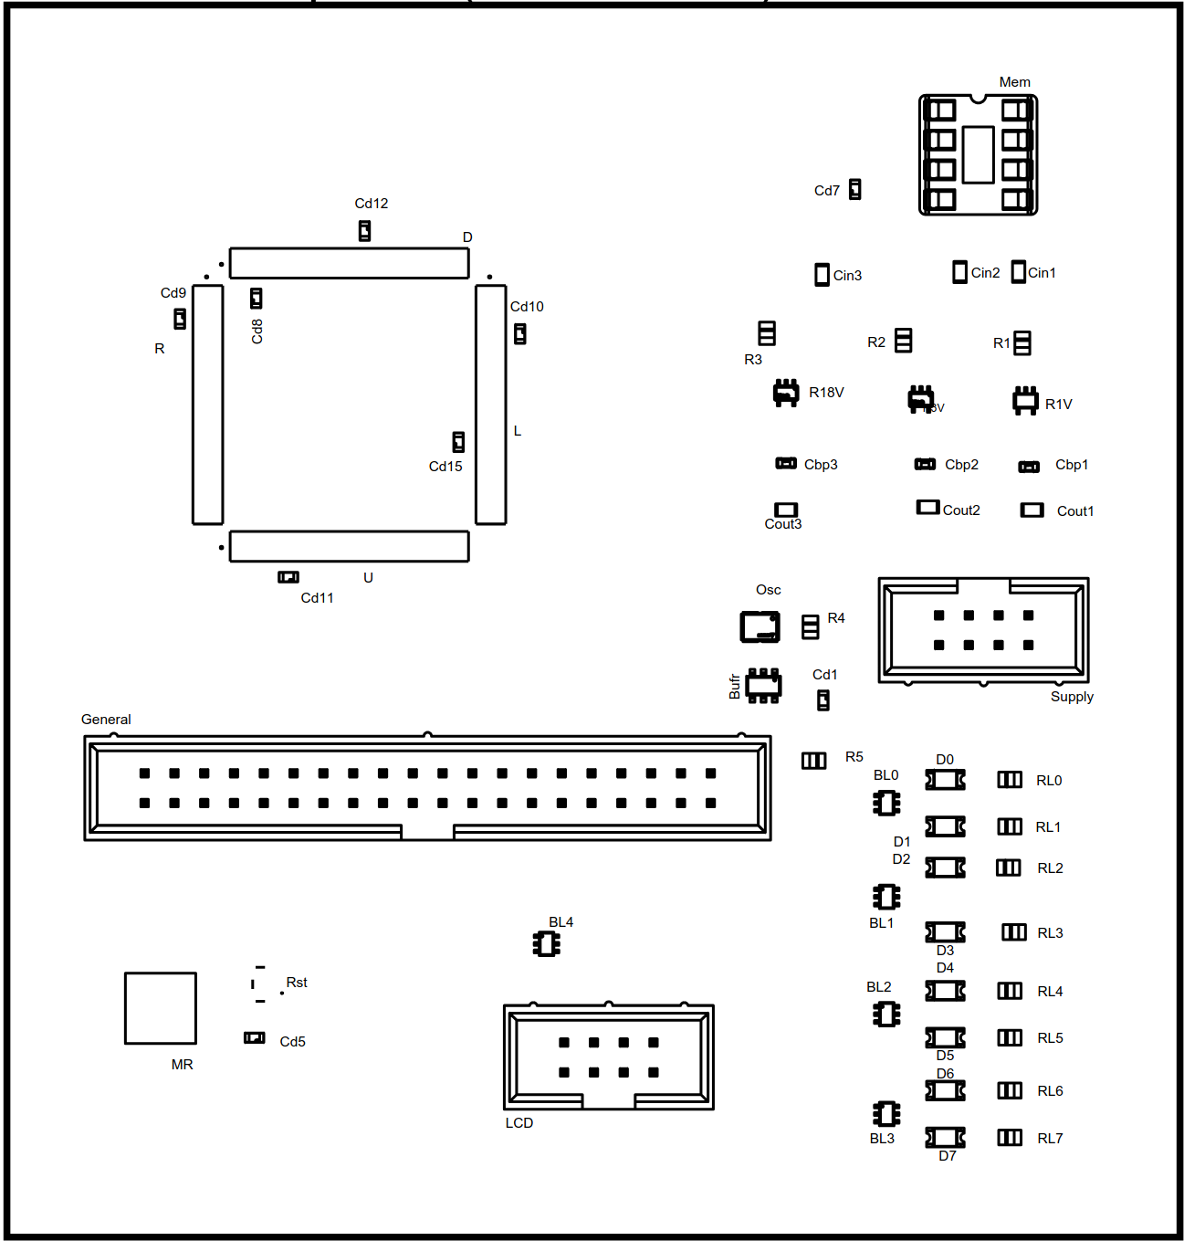
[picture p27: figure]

Figura 13: Vista superior del PCB

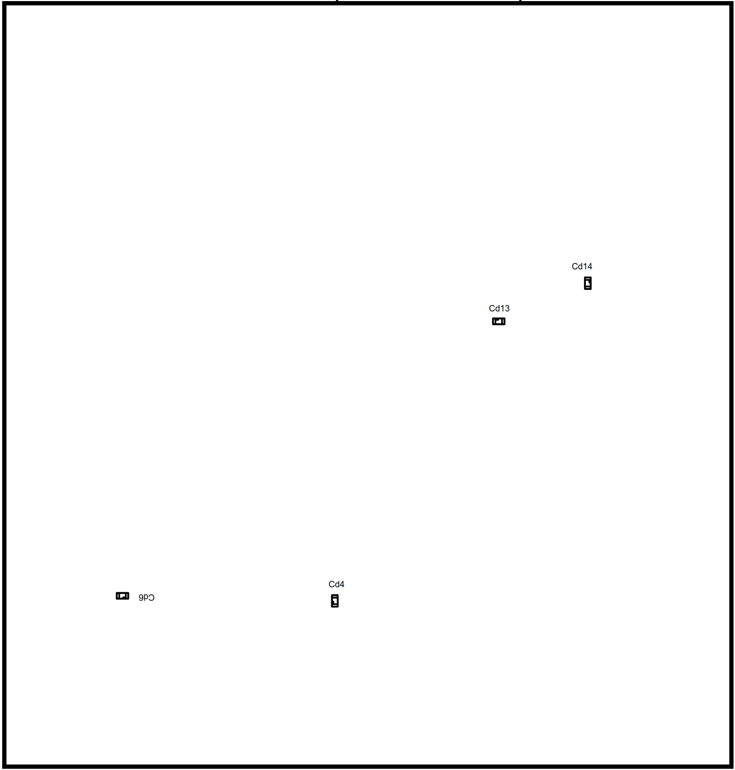
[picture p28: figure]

Figura 14: Vista inferior del PCB

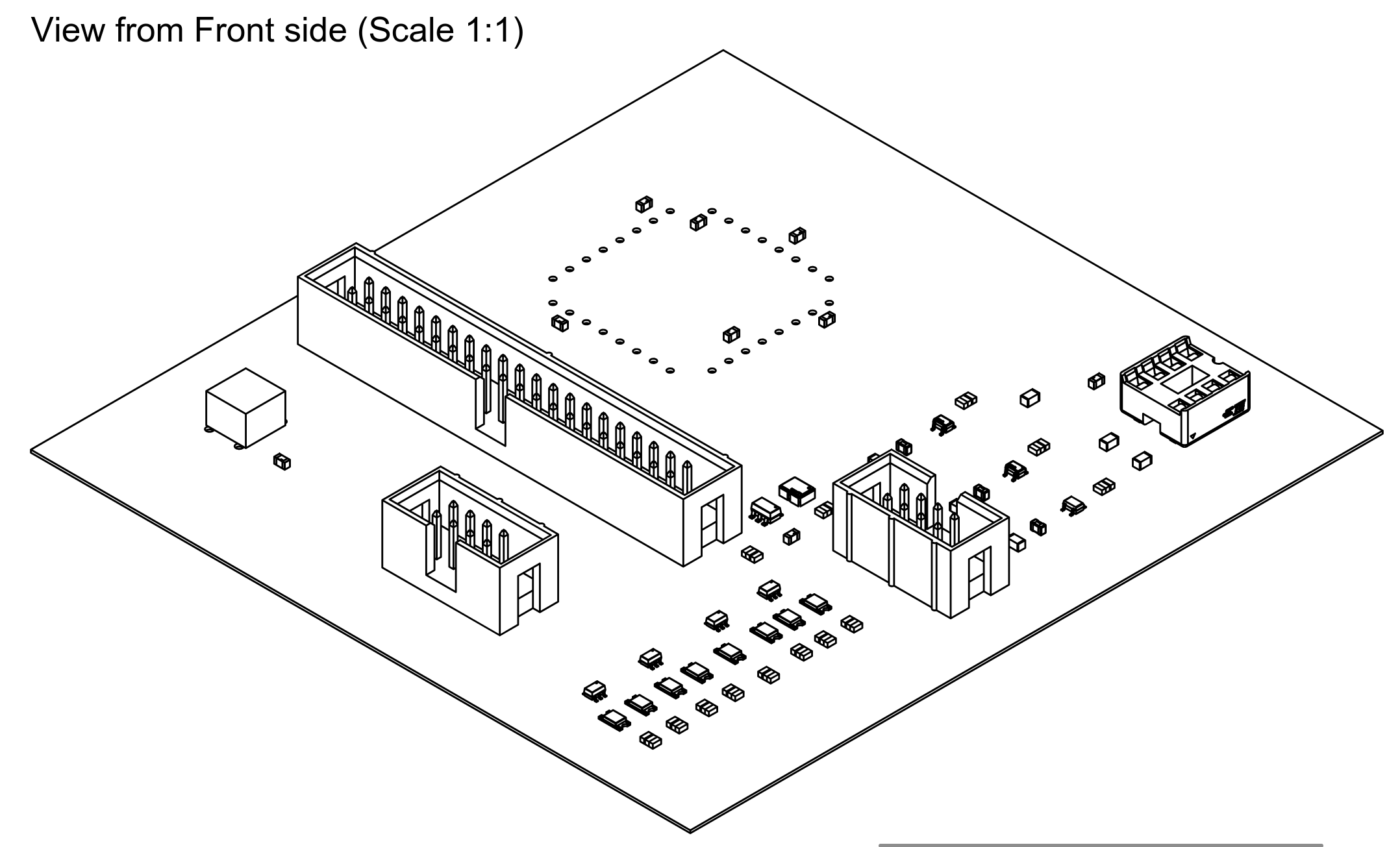
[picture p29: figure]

Figura 15: Vista frontal del PCB

### 4.3. Zonas críticas y ruteos relevantes

Durante el ruteo del sistema, se determinaron cuales subsistemas son los de mayor delicadeza y relevancia de diseño, debido a su importancia para el correcto funcionamiento del sistema, los cuales se aprecian en las figuras 16 y 17 los cuales se aprecian a continuación:

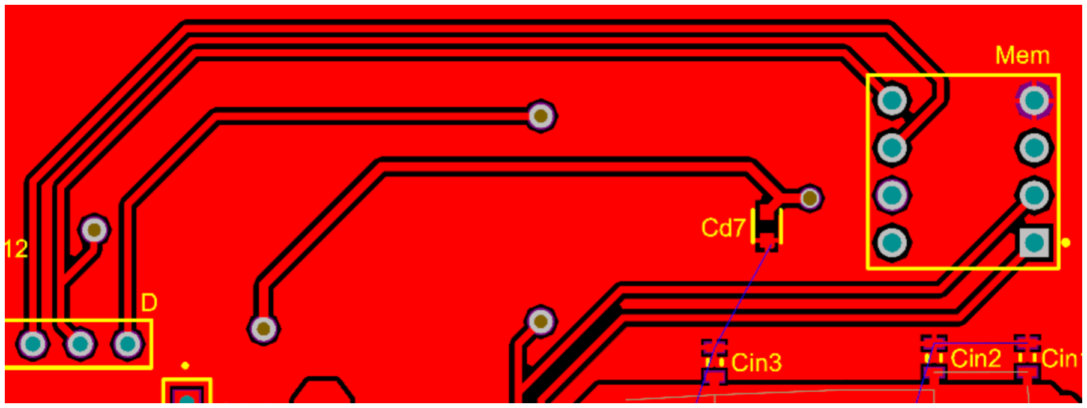
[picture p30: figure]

Figura 16: Subsistema relevante: Memoria externa

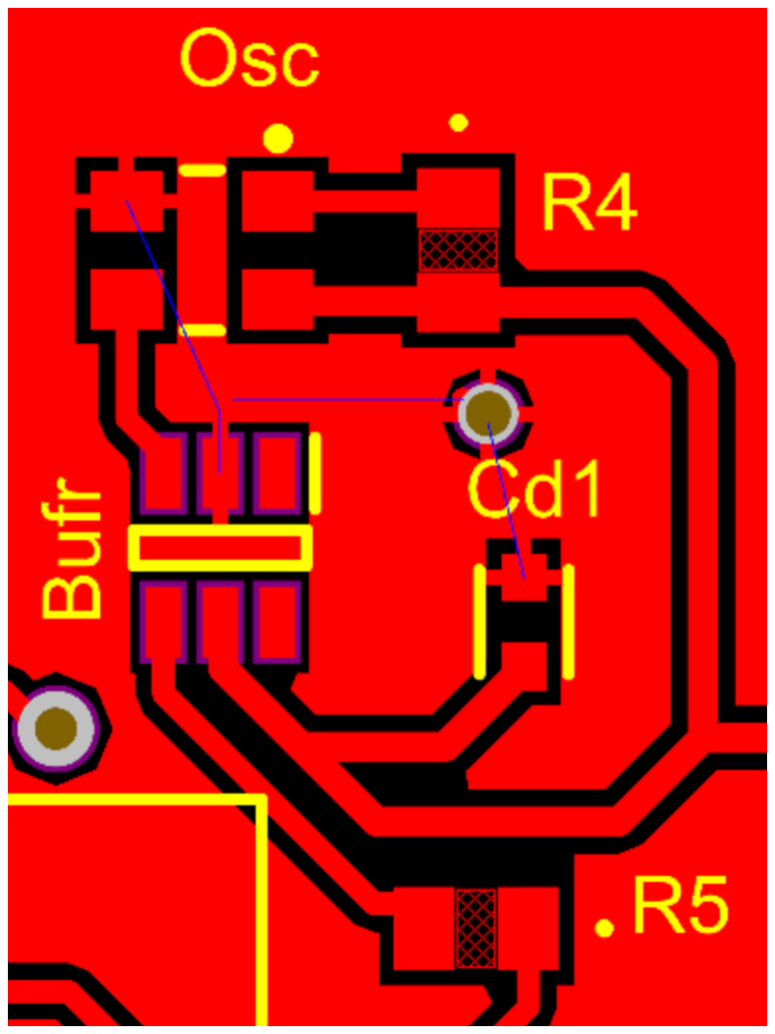
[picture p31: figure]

Figura 17: Subsistema relevante: CLK

## 5. Gestión y Planificación (Metodología Ágil)

### 5.1. Resultados sprint 1

Para el desarrollo de este sprint, se realizo una distribución de las tareas abordando el mismo concepto de distribuir los diferentes subsistemas para unirlos posteriormente.

Sebastián Barrantes Pérez: Realización del esquemático de la alimentación y conexión general

Christopher Quiros Cisneros: realización del esquemático de los LEDs, realización del esquemático del LCD, conexión general y control de las tareas de los sprint.

Samuel Valdivia Mejías: realización del esquemático del conector del Siwa, realización del esquemático del reset y realización del esquemático de la memoria externa.

Basandose en la figura 18, podemos apreciar como se completaron las tareas en las fechas asignadas, se alcanzaron a completar todos los entregables objetivo y se dejó la base lista para avanzar al diseño final. El progreso visualizado durante el desarrollo del sprint destaca una alta efectividad de parte de los participantes en el desarrollo de las tareas asignadas para esta etapa. Para esta etapa no se presentaron dificultad alguna en el desarrollo de las tareas.

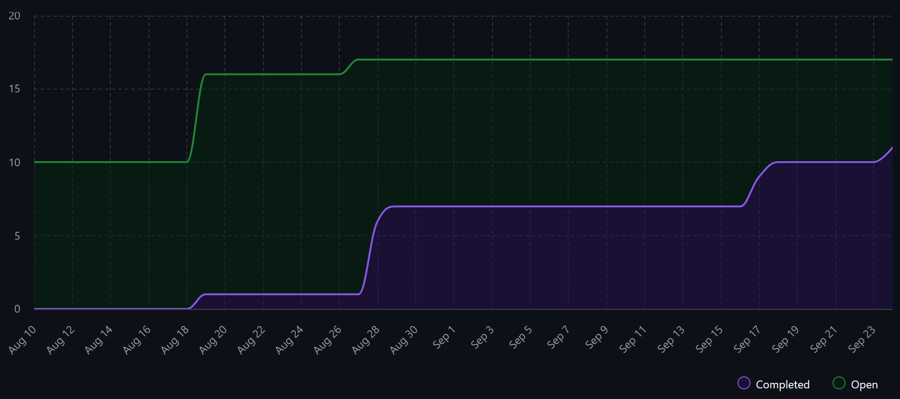
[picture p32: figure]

Figura 18: Burndown chart Sprint 1

### 5.2. Resultados sprint 2

Partiendo del punto final del sprint 1, se dio inicio a este segundo proceso de diseño. Partiendo de la misma planificación previamente usada, se importaron todos los componentes y el ruteo de los diferentes subsistemas consistieron en las tareas a realizar, junto con la verificación de errores, elección al layer que pertenece cada componente y demás.

Sebastián Barrantes Pérez: Realización del ruteo de la alimentación y realización del ruteo del Siwa de los diferentes subsistemas.

Christopher Quiros Cisneros: realización del ruteo de los LEDs, realización del ruteo del LCD, realización del ruteo del Siwa de los diferentes subsistemas y control de las tareas de los sprint y documentación.

Samuel Valdivia Mejías: realización del ruteo del reset, realización del ruteo de la memoria externa y realización del ruteo del Siwa de los diferentes subsistemas.

De igual manera, en base al burndown chart 19, se se mantuvo el trabajo eficaz, cumpliendo con las fechas asignadas y task asignadas, se alcanzaron a completar todos los entregables objetivo y se dejó la base lista para avanzar al diseño final. El progreso visualizado durante el desarrollo del sprint destaca una alta efectividad de parte de los participantes en el desarrollo de las tareas asignadas pero, en el proceso de asimilar mejor la aplicación Altium Designer, se presentaron errores leves y fáciles de solucionar. De igual manera, el PCB preliminar se modifico varias veces a fin de mejorar el diseño y prevenir futuras dificultades en el ensamblaje a futuro. Los task de este sprint 2 se iniciaron tarde, pero debido a dificultades de los integrantes, se asignaron tarde en el sprint.

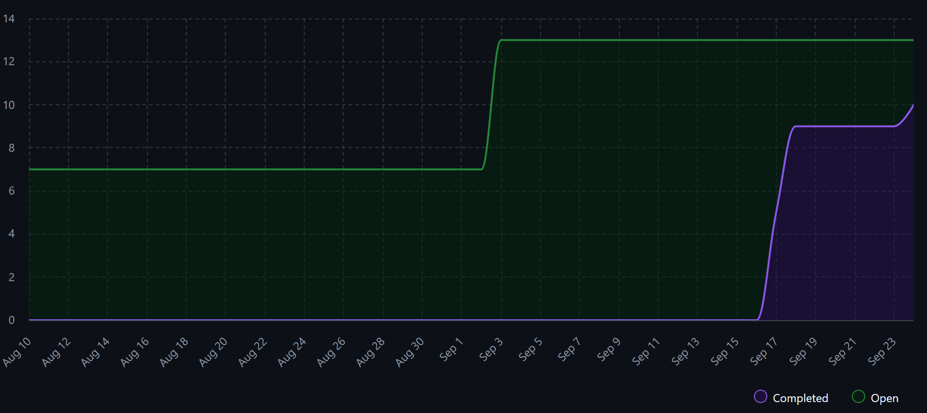
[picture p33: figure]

Figura 19: Burndown chart Sprint 2

## Referencias

[1] Abracon LLC, ASE3 Series — 1.8V CMOS Compatible SMD Crystal Oscillator (3.2×2.5×1.2 mm), Rev. 2021-10-20.
[2] Maxim Integrated, MAX8510/MAX8511/MAX8512 — Ultra-Low-Noise, High PSRR, Low-Dropout, 120mA Linear Regulators, Document 19-2732, Rev. 5, 05/2019.
[3] Diodes Incorporated, APX811/APX812 — 4-Pin Microprocessor Supervisor with Manual Reset, DS31960, Rev. 2, 10/2009.
[4] TE Connectivity, DIP Sockets — Quick Reference Guide, 01/2017.
[5] Nexperia B.V., 74LVC162244A; 74LVCH162244A: 16-bit buffer/line driver; 5 V tolerant; 3-state, Product data sheet Rev. 10 — 26 Apr 2024.
[6] Microchip Technology Inc., PL133-37 Low-Power Inverting/Non-Inverting 1:3 Fanout Buffer, DS20006403A, 2020.
[7] Microchip Technology Inc., SST25WF080B — 8-Mbit 1.8 V SPI Serial Flash, 09/14/2021.
[8] Newhaven Display, NHD-0216MW-IB3 2x16 OLED Character Display — Datasheet Rev. 3, 08/31/2023.
[9] QT-Brightek, QBLP595 Series 0402 LEDs — Datasheet v1.4, 02/15/2025.
[10] TAIYO YUDEN, Soft Termination MLCC—MAJCU168BB7104KTEA01, 0.1 µF, 50 V, X7R, 0603, 03/08/2024.
[11] Würth Elektronik, WR-BHD Male Box Header 2.54 mm — 61204021621 (40-pin), 08/30/2022.
[12] Würth Elektronik, WR-BHD Male Box Header 2.54 mm — 61200821621 (8-pin), 08/30/2022.

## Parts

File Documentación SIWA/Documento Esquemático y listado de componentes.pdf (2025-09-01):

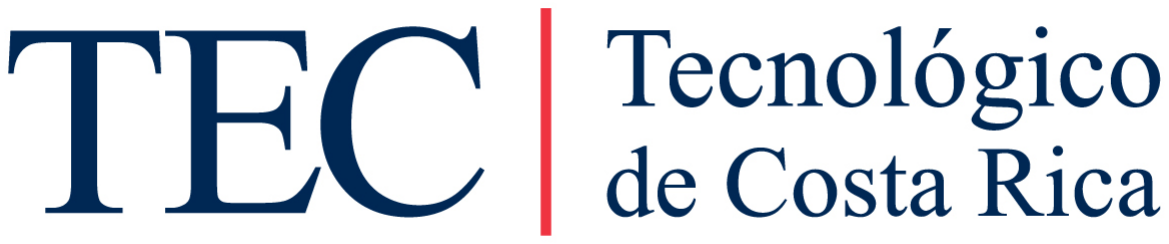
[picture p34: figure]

# Escuela de Ingeniería Electrónica Escuela de Ingeniería Mecatrónica Control Automático

# Diseño de esquemático para PCB del SIWA

Profesor:
Renato Rimolo

Integrantes:
Hender Samuel Valdivia Mejia hvaldivia@estudiantec.cr

Sebastián Barrantes Pérez 702870652@estudiantec.cr

Christopher Quiros Cisneros acostchris@estudiantec.cr

Cartago, Costa Rica
29 de Agosto de 2025

## 0.1. Esquemático

En esta sección se muestran y explican algunos detalles relacionados al esquemático del diseño de la placa de conexiones del procesador SIWA:

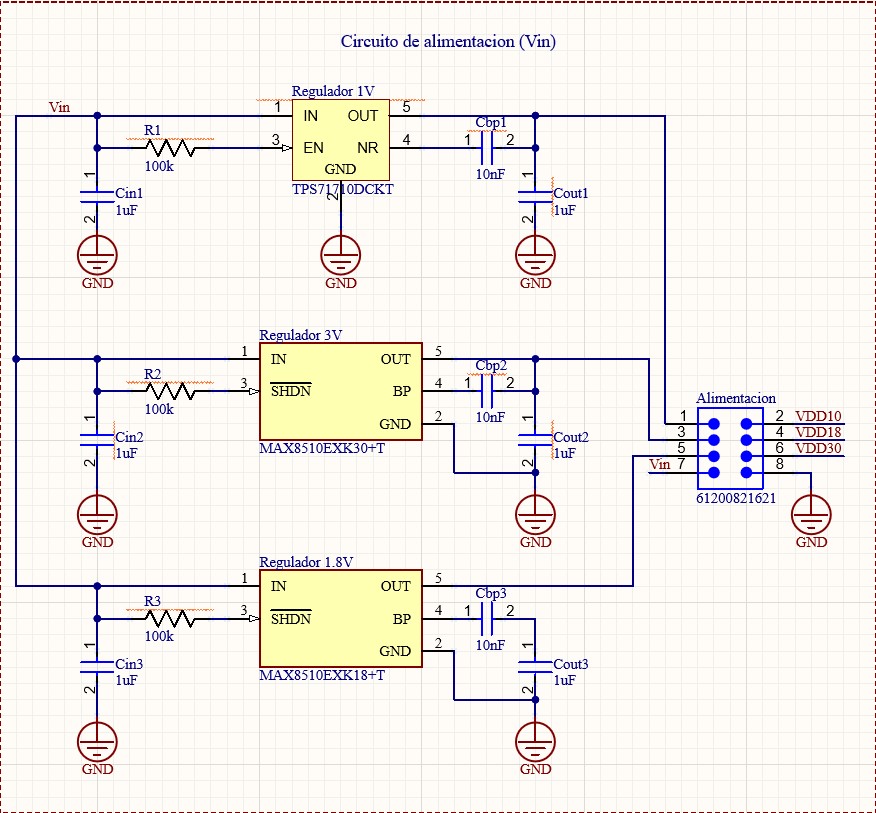
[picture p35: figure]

Figura 1: Reguladores de voltaje

Inicialmente en la Fig 1 se muestran los reguladores en su configuración predeterminada por el fabricante para su funcionamiento y entrega de alimentación de 1V, 3V y 1.8V respectivamente a como se muestra en la imagen. Cada uno de estos reguladores tiene una capacitancia de desacople en la entrada, una resistencia de pull-en su pin de ENABLE/SHDN, además de un capacitor de bypass para disminuir el ruido en las alimentaciones y una capacitancia de salida. Mediante un header se conectan estas salidas para asegurar DFM.

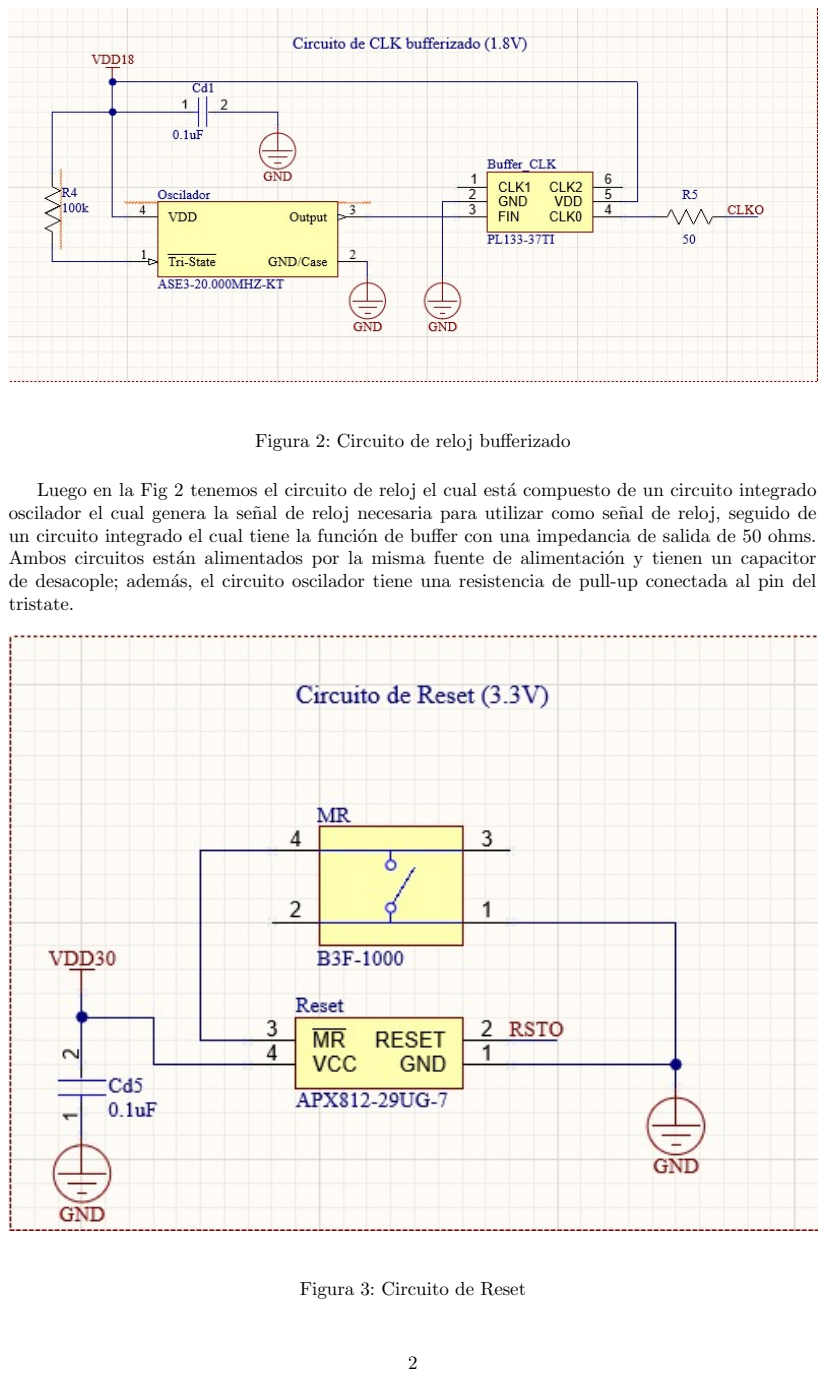
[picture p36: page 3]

Figura 2: Circuito de reloj bufferizado

Luego en la Fig 2 tenemos el circuito de reloj el cual está compuesto de un circuito integrado oscilador el cual genera la señal de reloj necesaria para utilizar como señal de reloj, seguido de un circuito integrado el cual tiene la función de buffer con una impedancia de salida de 50 ohms. Ambos circuitos están alimentados por la misma fuente de alimentación y tienen un capacitor de desacople; además, el circuito oscilador tiene una resistencia de pull-up conectada al pin del tristate.

Figura 3: Circuito de Reset

En la Fig 3 se tiene el circuito de reset con un circuito integrado conectado a un push-button en el pin de MR teniendo una función de enable para el circuito integrado del reset.

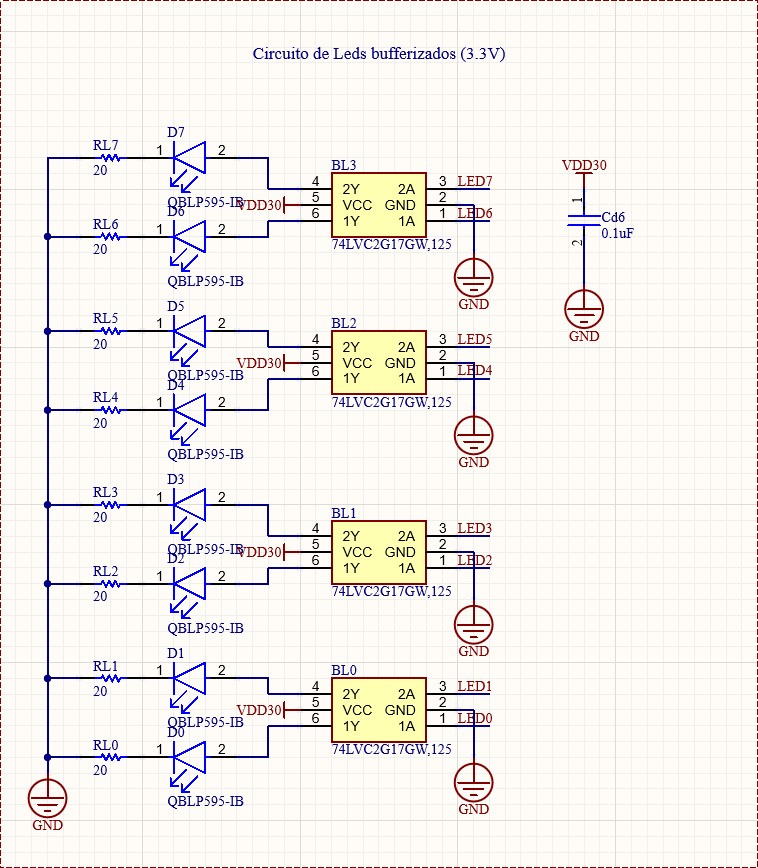
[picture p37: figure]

Figura 4: Circuito de LEDs

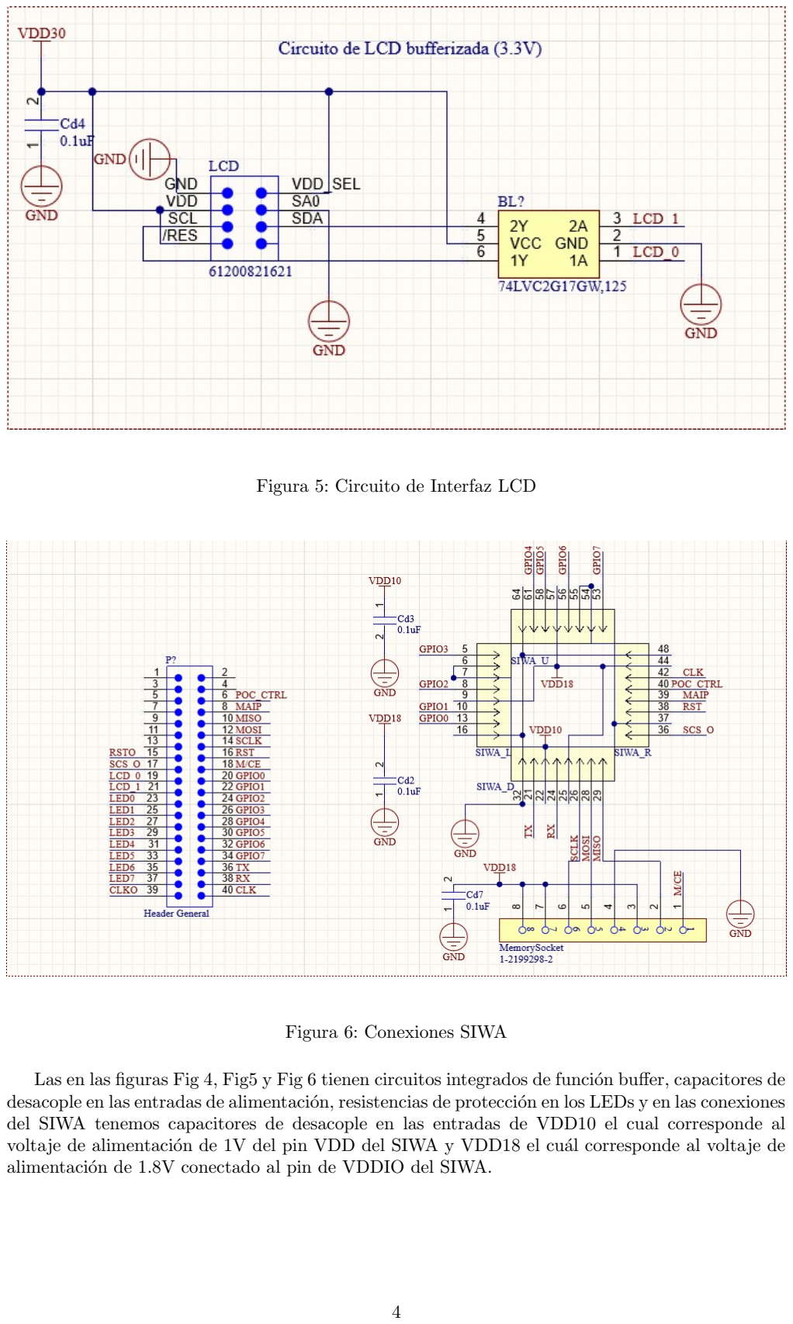
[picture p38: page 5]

Figura 5: Circuito de Interfaz LCD

Figura 6: Conexiones SIWA

Las en las figuras Fig 4, Fig5 y Fig 6 tienen circuitos integrados de función buffer, capacitores de desacople en las entradas de alimentación, resistencias de protección en los LEDs y en las conexiones del SIWA tenemos capacitores de desacople en las entradas de VDD10 el cual corresponde al voltaje de alimentación de 1V del pin VDD del SIWA y VDD18 el cuál corresponde al voltaje de alimentación de 1.8V conectado al pin de VDDIO del SIWA.

## 0.2. Lista de componentes

Cantidad | Componente | Modelo
2 | Header 8x1 | 61200821621
5 | Buffer LEDs y LCD | 74LVC2G17GW,125
1 | CI Buffer Reloj | PL133-37TI-R
3 | Capacitores 10 nF | CGA3E1C0G2A103J080AC
7 | Capacitores 0.1 uF | KGM15BR71H104JT
6 | Capacitores 1 uF | TACL105K006XTA
8 | LEDs | QBLP595-IB
1 | Memory Base DIP | 1-2199298-2
1 | Switch Button | B3F-1000
1 | CI Oscilador | ASE3-20.000MHZ-KT
1 | Header General | 61204021621
4 | Resistencias 100kΩ | PEP0805Y1003BNTA
1 | *Resistencia 50Ω | HPT2012-50-T1
1 | Regulador 1V | TPS71710DCKT
1 | Regulador 1.8V | MAX8510EXK18+T
1 | Regulador 3 V | MAX8510EXK18+T
1 | CI Reset | APX812-29UG-7
8 | Resistencias LEDs | ERJ-3EKF20R0V
4 | Conector Interfaz SIWA | PPTC081LFBN-RC

Cuadro 1: Listado de componentes y modelos utilizados en el esquemático

*Nota: Esta resistencia aparece en el archivo esquemático y en excel BoM como R5 con un valor de 100k pero es debido a que el modelo utilizado fue el mismo de las resistencias de 100k, el modelo necesario que cumple las especificaciones y el valor de 50 Ω para esta resistencia es el que se muestra en la tabla.

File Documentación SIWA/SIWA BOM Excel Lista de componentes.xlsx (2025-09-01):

Line # | Name | Description | Designator | Revision ID | Revision State | Revision Status | Quantity | Manufacturer 1 | Manufacturer Part Number 1 | Manufacturer Lifecycle 1 | Supplier 1 | Supplier Part Number 1 | Supplier Unit Price 1 | Supplier Subtotal 1
 | 61200821621 |  | Alimentacion, LCD | CMP-1502-00006-2 | Released | Up to date | 2 | Wurth Elektronik | 61200821621 | Unknown | Mouser | 710-61200821621 | 0.97 | 1.94
 | 74LVC2G17GW,125 | Integrated Circuit | BL0, BL1, BL2, BL3, BL4 |  | Not managed |  | 5
 | PL133-37TI | Integrated Circuit | Buffer_CLK |  | Not managed |  | 1
 | CGA3E1C0G2A103J080AC | Cap Ceramic 10nF 100V C0G 5% Pad SMD 0603 +125°C Automotive T/R | Cbp1, Cbp2, Cbp3 | CMP-08246-000560-1 | New From Design | Up to date | 3 | TDK | CGA3E1C0G2A103J080AC | Volume Production | Newark | 68AC4495 | 0.078 | 0.234
 | KGM15BR71H104JT | KGM15BR71H104JT Cap Cer 0.1UF 50V X7R 0603 | Cd1, Cd2, Cd3, Cd4, Cd5, Cd6, Cd7 | CMP-07738-136560482-1 | New From Design | Up to date | 7 | KYOCERA AVX | KGM15BR71H104JT | Volume Production | Mouser | 581-KGM15BR71H104JT | 0.051 | 0.51
 | TACL105K006XTA |  | Cin1, Cin2, Cin3, Cout1, Cout2, Cout3 | CMP-2006-00183-1 | Released | Up to date | 6 | KYOCERA AVX | TACL105K006XTA | Volume Production | Arrow Electronics | TACL105K006XTA | 0.394 | 2.36
 | QBLP595-IB | LED BLUE CLEAR 0402 SMD | D0, D1, D2, D3, D4, D5, D6, D7 | CMP-113271-000002-1 | New From Design | Up to date | 8 | QT Brightek | QBLP595-IB | Unknown | Farnell | 4469606 | 0.17979 | 1.8
 | 1-2199298-2 | CONN IC DIP SOCKET 8POS TIN | MemorySocket | CMP-03370-000009-1 | New From Design | Up to date | 1 | TE Connectivity | 1-2199298-2 | Volume Production | RS (Formerly Allied Electronics) | 71373899 | 0.067 | 0.067
 | B3F-1000 | Tactile Switch, SPST-NO, 0.05 A, 5 to 24 V, -25 to 70 degC, 4-Pin THD, RoHS, Bulk | MR | CMP-1677-00002-1 | Released | Up to date | 1 | Omron | B3F-1000 | Volume Production | Avnet | B3F1000 | 0.16998 | 0.16998
 | ASE3-20.000MHZ-KT | XTAL OSC XO 20.0000MHZ CMOS SMD | Oscilador | CMP-27762-010045-1 | New From Design | Up to date | 1 | Abracon | ASE3-20.000MHZ-KT | Volume Production
 | 61204021621 |  | P1 | CMP-1502-00015-3 | Released | Up to date | 1 | Wurth Elektronik | 61204021621 | Unknown | Mouser | 710-61204021621 | 1.09 | 1.09
 | PEP0805Y1003BNTA | PEP0805Y1003BNTA Resistor High Precision Thin Film 0805 100k Ohm 0.1% 1/2W ±10ppm/°C Molded T/R | R1, R2, R3, R4, R5 | CMP-00030-123138495-1 | New From Design | Up to date | 5 | Vishay | PEP0805Y1003BNTA | Volume Production | Newark | 83AJ0654 | 3.97 | 19.85
 | TPS71710DCKT | Single Output High PSRR LDO, 150 mA, Fixed 1 V Output, 2.5 to 6.5 V Input, with Low IQ, 5-pin SC70 (DCK), -40 to 85 degC, Green (RoHS & no Sb/Br) | Regulador 1V | CMP-0394-00843-2 | Released | Up to date | 1 | Texas Instruments | TPS71710DCKT | Volume Production | Arrow Electronics | TPS71710DCKT | 0.0897 | 0.0897
 | MAX8510EXK18+T | IC REG LINEAR 1.8V 120MA SC70-5 | Regulador 1.8V | CMP-0246-00401-2 | Released | Up to date | 1 | Analog Devices | MAX8510EXK18+T | Volume Production | Newark | 73Y6124 | 0.225 | 0.225
 | MAX8510EXK30+T | IC REG LINEAR 3V 120MA SC70-5 | Regulador 3V | CMP-0246-00520-2 | Released | Up to date | 1 | Maxim | MAX8510EXK30+T | Unknown
 | APX812-29UG-7 | I_O=20mA | Reset |  | Not managed |  | 1
 | ERJ-3EKF20R0V |  | RL0, RL1, RL2, RL3, RL4, RL5, RL6, RL7 | CMP-2000-00325-1 | Released | Up to date | 8 | Panasonic | ERJ-3EKF20R0V | Volume Production | Mouser | 667-ERJ-3EKF20R0V | 0.021 | 0.21
 | PPTC081LFBN-RC | Description | SIWA_D, SIWA_L, SIWA_R, SIWA_U |  | Not managed |  | 4

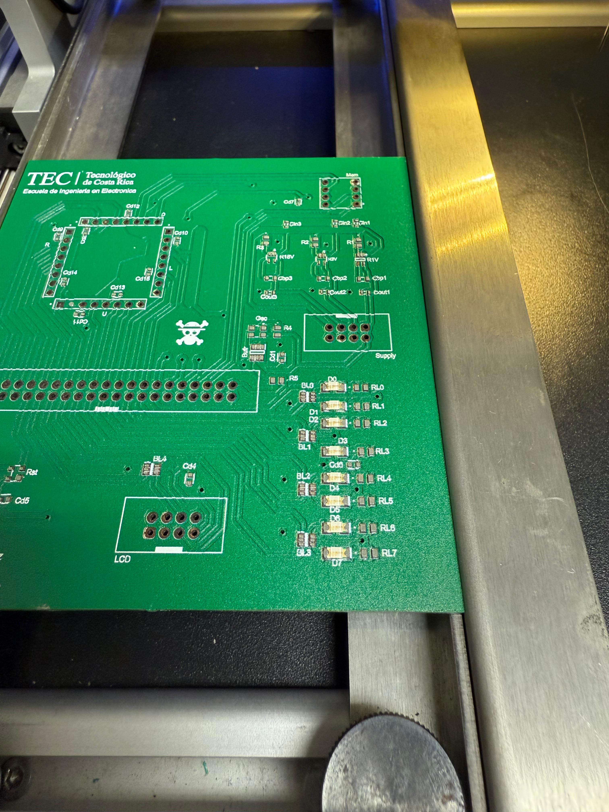
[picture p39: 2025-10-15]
Documentación SIWA/component placement.jpeg

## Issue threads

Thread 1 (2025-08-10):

Diseño del circuito para conectar el microcontrolador Siwa

SebasJB, 2025-08-10:
##Estimación de esfuerzo:
Sin asignar

##Criterios de aceptación:

- El circuito debe cumplir con las especificaciones eléctricas del Siwa.
- Debe incluir interfaces necesarias para programación y depuración.
- Se debe validar que no haya errores de conexión antes de pasar a PCB.

Closed 2025-09-17.

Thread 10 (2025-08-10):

Documentación del proyecto

SebasJB, 2025-08-10:
##Estimación del esfuerzo:
Sin asignar

##Criterios de aceptación:

- Incluir diagramas, esquemáticos, resultados de medición y conclusiones.
- El documento debe estar en el formato definido para el mismo.

Closed 2025-09-24.

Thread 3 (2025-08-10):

Diseño de la tarjeta de prueba (PCB)

SebasJB, 2025-08-10:
##Estimación del esfuerzo:
Sin asignar

##Criterios de aceptación:

- Cumplir con reglas de diseño y espaciamiento del fabricante.
- Incluir puntos de prueba y conectores accesibles.

Closed 2025-09-17.

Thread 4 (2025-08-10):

Validación prefabricación y DFM de la tarjeta de prueba

SebasJB, 2025-08-10:
##Estimación del esfuerzo:
Sin asignar

##Criterios de aceptación:
- Pasar revisión DFM y checklist de manufactura.
- Corregir cualquier error detectado antes de enviar a producción.

Closed 2025-09-18.

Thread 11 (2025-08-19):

Buscar hojas de datos

ValdiviaM, 2025-08-19:
Buscar hojas de datos de las siguientes partes de la placa:

- [x] Alimentación y reloj (Asignado: Sebastian)
- [x] Pantalla LCD, Memoria y LEDs (Asignado: Christopher)
- [x] Circuito de Reset e interfaces de pines (Asignado: Samuel)

Closed 2025-08-19.

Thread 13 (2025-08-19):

Crear esquemático para circuito de reset e interfaces

ValdiviaM, 2025-08-19:

Closed 2025-08-28.

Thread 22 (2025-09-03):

Ruteo de señales críticas

CiQiuu, 2025-09-03:
Trazar reloj, SPI, UART y buses sensibles asegurando impedancias y minimizando interferencias.

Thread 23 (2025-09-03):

Generación de archivos de salida

CiQiuu, 2025-09-03:
Subtareas:

- Configurar un archivo Output Job (.OutJob)
- Exportar Gerber Files.
- Generar Drill Files.
- Regenerar BoM ante posible cambio.
- Generar los archivos de Pick & Place.
- Exportar el modelo 3D
- Comprimir todo en un paquete ZIP final para envío al fabricante: Gerbers, Drill Files, BoM, Pick & Place, planos.

Closed 2025-09-18.

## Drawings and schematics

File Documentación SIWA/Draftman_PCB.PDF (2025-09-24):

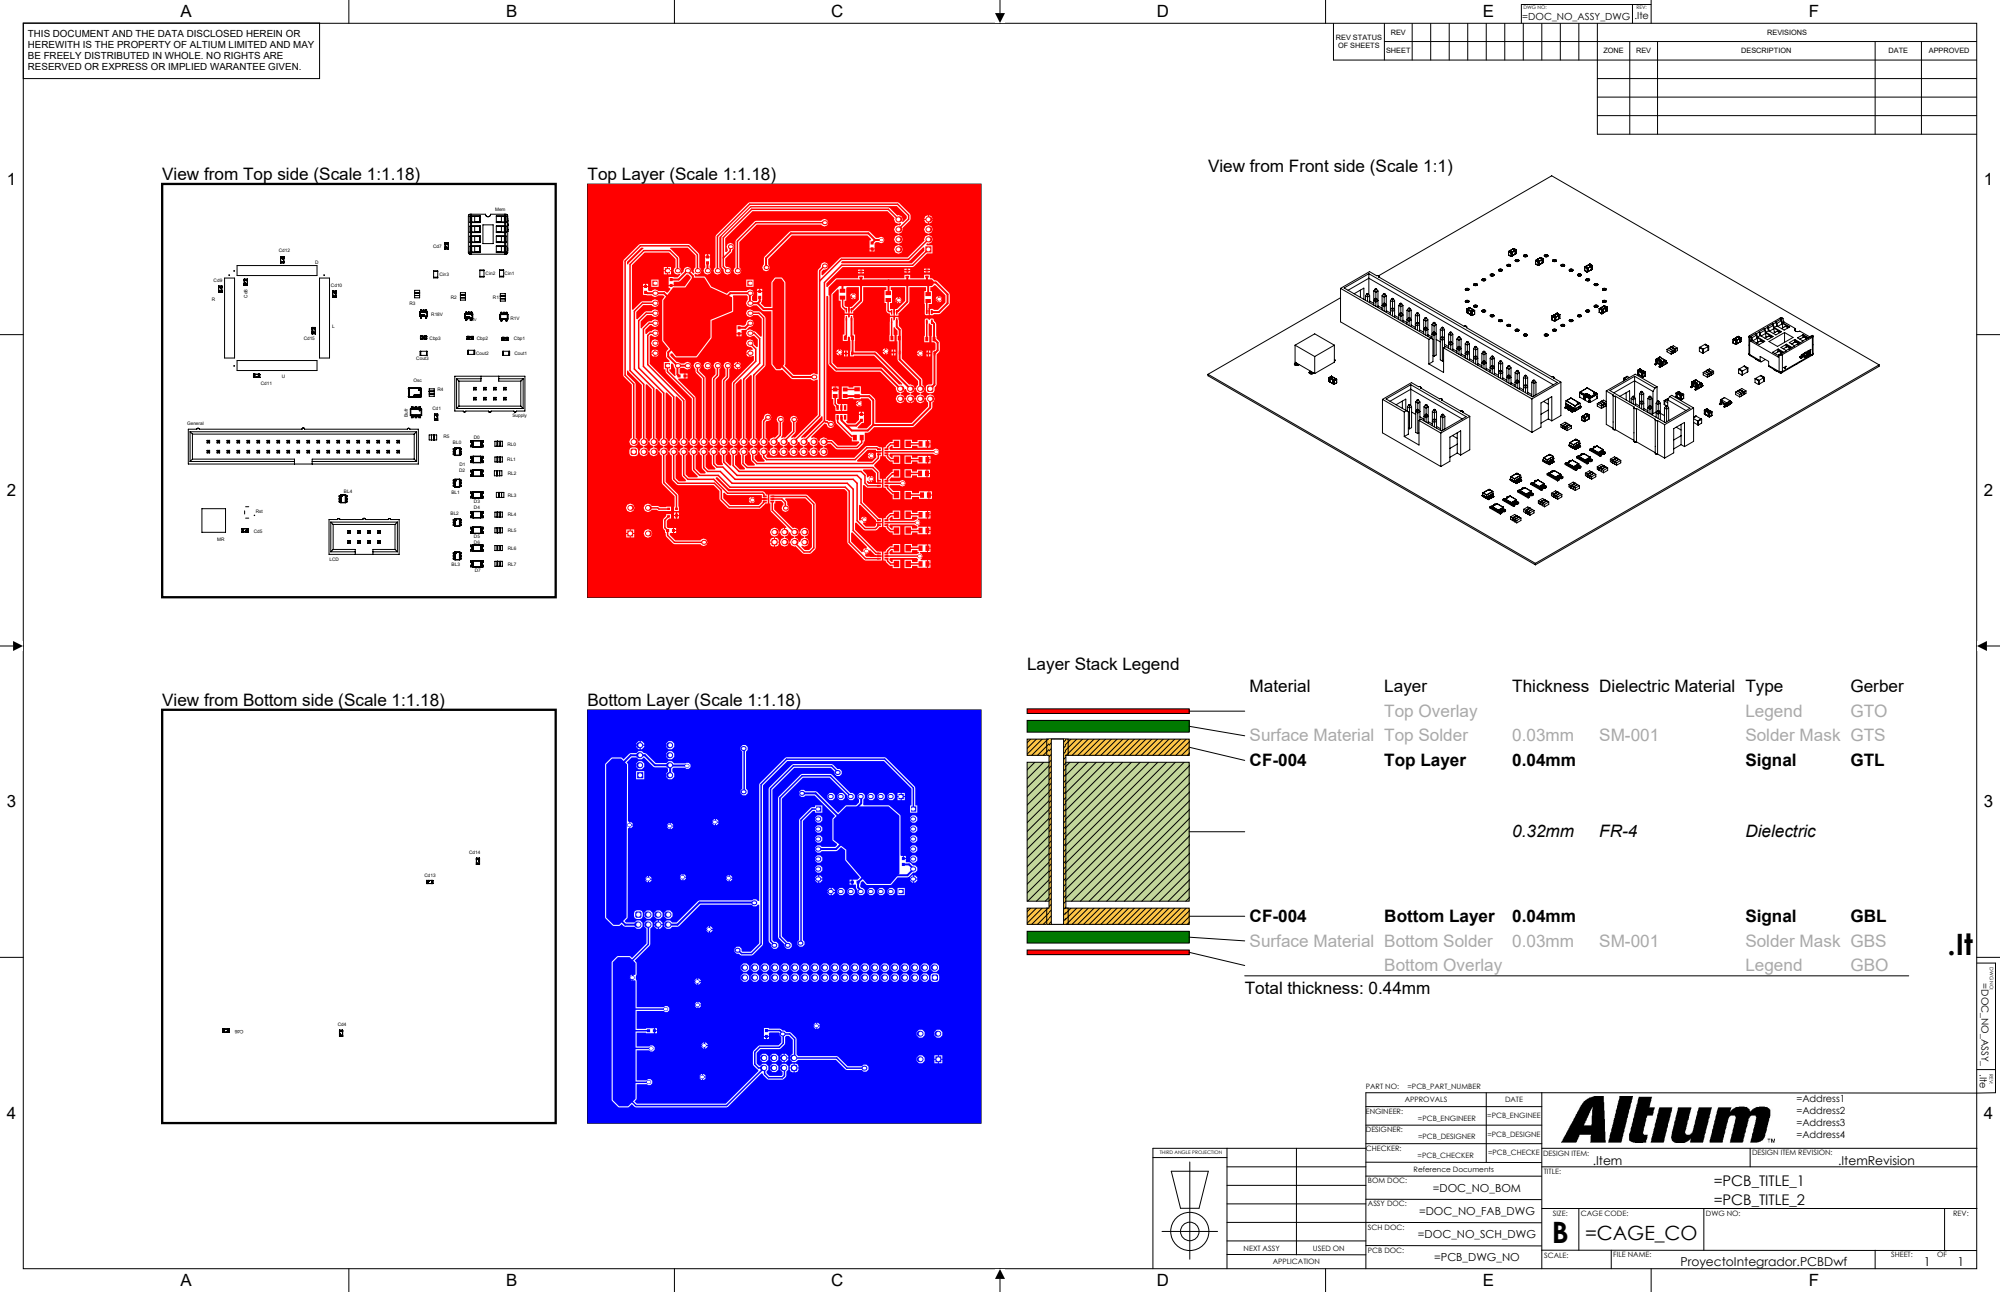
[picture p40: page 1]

HEREWITH IS THE PROPERTY OF ALTIUM LIMITED AND MAY
BE FREELY DISTRIBUTED IN WHOLE. NO RIGHTS ARE
RESERVED OR EXPRESS OR IMPLIED WARANTEE GIVEN.

View from Front side (Scale 1:1)

APPROVALS | DATE

ENGINEER: =PCB_ENGINEER | =PCB_ENGINEE

DESIGNER: =PCB_DESIGNER | =PCB_DESIGNE

THIRD ANGLE PROJECTION

CHECKER: =PCB_CHECKER | =PCB_CHECKE

SCH DOC: =DOC_NO_SCH_DWG

NEXT ASSY | USED ON

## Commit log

2025-08-19 Agrega hojas de datos a usar
2025-08-21 Datasheets de la memoria y LCD
2025-08-23 Agrega header de interfaz con SIWA
2025-08-23 Cambio de hoja de datos LEDs
2025-08-24 Agrega esquematico del siwa con reset y leds
    [SIWA1-0.SchDoc]
2025-08-24 Esquemático de alimentación y reloj
    [Esquemático Alimentación y reloj.SchDoc]
2025-08-24 Esquematico memoria
    [EsquematicoExternalMemory.SchDoc]
2025-08-24 Esquematico general
    [SIWA1-0.SchDoc]
2025-08-25 Reordena esquemático y separa reset del siwa
    [SIWA1-0.SchDoc]
2025-08-27 Actualiza esquematico segun feedback del profe
    [SIWA1-0.SchDoc]
2025-08-29 Corrección de errores esquemático del SIWA
    [SIWA1-0.SchDoc]
2025-08-29 Agrega BOM del proyecto
2025-08-29 Documentación de esquemático y componentes
2025-08-30 Correcciones y actualizaciones
    [SIWA BOM Excel Lista de componentes.xlsx]
2025-09-01 Corrección header, capacitores y resistencias
2025-09-08 Agrega PCB sin rutear
    [ProyectoIntegrador.PcbDoc]
2025-09-08 Routea la LCD
    [ProyectoIntegrador.PcbDoc]
2025-09-08 Cambia errores de nombre de pines
    [SIWA1-0.SchDoc]
2025-09-13 Cambios en ruteo de SIWA
2025-09-18 Agrega plano de tierra y alimentaciones
2025-09-18 Agrega plano de tierra capa superior
2025-09-19 Cambios de errores en Islas
    Aplicación de Serigrafía en nombres y diseños de imagen, acomodo de los nombres de los componentes, y rediseño de tierras innecesarias
2025-09-19 Arreglo de espacio entre pistas
2025-09-22 Agrega capacitores de desacople
2025-09-23 Agrega documentos de output
2025-09-24 BoM Preliminar
2025-09-24 PCB Preliminar
    [ProyectoIntegrador.PcbDoc]
2025-09-24 Archivo Draftman PCB
